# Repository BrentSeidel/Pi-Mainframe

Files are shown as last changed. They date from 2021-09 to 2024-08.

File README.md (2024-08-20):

# Pi-Mainframe
Simulated mainframe computer based on a Raspberry Pi

[]
(https://alire.ada.dev/crates/blinkenlights.html)

When I was a young lad, computers had complicated panels filled with
switches and lights.  Sadly, these disappeared as I got older.

This project is an attempt to recreate the feel of old mainframe computers
using a Raspberry Pi 3 and some other assorted parts that I had laying
around.  The actual boxes and panels are 3D printed.

Here is an example system.  Note that it is fairly modular and the
modules can be attached in different ways.
System Front

Back of system
System Back

## Note
This is still very much a work in progress and things will change.

This project requires 3D printing, making PCBs, soldering, and building
software from source.  It might be a good project for an undergraduate
engineering program.

## Power
I originally used a random micro USB power supply for the Pi 3 that is
running the simulation.  It would complain about low voltage and
occasionally reboot.  I just replaced it with the official Raspberry Pi
power supply and it is not complaining about low voltage.  Time will
tell if it is more stable.

Ultimately, there will be limits to how much power you can get out of
the Raspberry Pi.  There are ways to reduce the power needed.  The first
thing that I would try would be to increase the value of the resistors
for the LEDs.  This would also reduce the brightness so you may wish to
do this as well, if the LEDs are too bright.  A little experimentation
will be needed to determine the proper value.  From a BOM viewpoint,
using the same resistors for both the switches and LEDs would be a win.

## PCBs
Three printed circuit boards have been designed to eliminate some of the
tedious soldering.  Using the PCBs make assembly much easier and the
resulting project much less of a mess of wires.

### IO Board PCB
The I/O board PCB has been created and tested.  The schematics and PCB
layout have been moved to the Circuits reporitory.  Documentation and
assembly instructions for it have been created there.

### Breakout PCB
A breakout PCB has been developed for breaking out the 10 conductor
ribbon cables that are being used for the I2C bus, and other uses.  It
is also in the Circuits repository.

### LED PCB
A PCB has been developed for holding the LEDs.  This required some redesign
to the panels.  However it eliminates the soldering of wires directly to
the LED leads.  The LED PCB can also be fairly easily added to and
removed from panels should you wish to, for example, use LEDs of different
colors.

## Dependencies
This depends on the following repositories:
* https://github.com/BrentSeidel/BBS-Ada.git
* https://github.com/BrentSeidel/BBS-BBB-Ada.git
* https://github.com/BrentSeidel/Ada-Web-Server.git
* https://github.com/BrentSeidel/Things.git
* https://github.com/BrentSeidel/Sim-CPU.git
* https://github.com/BrentSeidel/Circuits.git

If you are actually interested in simulating old computers, you can
download and build simh from github at https://github.com/simh/simh.git
I was able to get the PDP-11 sim to build (I haven't tried others) and
run on a Raspberry Pi.  As far as I know, it has no support for blinking
lights.

You could, of course run simh in parallel with this project giving a
CPU simulation as well as lights and switches.  Unfortunately, they would
be completely independant.  Someday, perhaps this will change.

## Assembly
This project will require quite a bit of 3D printing and soldering.  The
included documentation includes a parts list.  Read the documentation
first, then download the dependencies repositories.  Finally decided
how big of a system you want.
1. Slice the 3D models and start them printing.  This will take a while,
   so start this first and then work on other things while they are printing.
2. Install Raspberian on the Raspberry Pi and install the following packages:
   * avahi - This allows discovery on your local network
   * gnat - The GNU Ada distribution
   * gprbuild - Used for building Ada software
3. Build the software.  If there are errors about missing "obj" directories,
   create the directories.
4. Start soldering the various boards and cables.
5. As panels come off the printer, install LEDs and switches as appropriate
6. As the trays come off the printer, install the boards and connectors.
7. Once everything is printed, put all the pieces together.

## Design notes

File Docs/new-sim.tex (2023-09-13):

\documentclass[10pt, openany]{book}

\usepackage{fancyhdr}
\usepackage{imakeidx}

\usepackage{amsmath}
\usepackage{amsfonts}

\usepackage{geometry}
\geometry{letterpaper}

\usepackage{fancyvrb}
\usepackage{fancybox}

\usepackage{url}
\usepackage{gensymb}
\usepackage{multicol}
\usepackage{tabularx}
%
% Rules to allow import of graphics files in EPS format
%
\usepackage{graphicx}
\DeclareGraphicsExtensions{.eps}
\DeclareGraphicsRule{.eps}{eps}{.eps}{}
%
% Macro definitions
%
\newcommand{\switch}[2]{``#1''/``#2''}
\newcommand{\position}[1]{``#1''}
%
% Front Matter
%
\title{Raspberry Pi Based Mainframe Simulator}
\author{Brent Seidel \\ Phoenix, AZ}
\date{ \today }
%========================================================
%%% BEGIN DOCUMENT
\begin{document}
%
% Produce the front matter
%
\frontmatter
\maketitle
\begin{center}
This document is \copyright 2023 Brent Seidel.  All rights reserved.

\paragraph{}Note that this is a draft version and not the final version for publication.
\end{center}
\tableofcontents
\listoffigures
\listoftables

\mainmatter
%----------------------------------------------------------
\chapter{Introduction}
A rather simplistic view is that this provides a way to get a Raspberry Pi to blink some LEDs and read some switches.  However, this hardware could be modified for a number of other applications that require lots of discrete I/O, such as burglar alarms or sprinkler controls.

\section{Parts}
\subsection{3D Printing}
A fair bit of 3D printing is required, so having lots of filament is a good idea.  Labels on the panels are done by (on my printer with a 0.15mm layer height) printing 2 layers of the panel color, then 3 layers of a contrasting color for the text, and then the rest in the panel color.  The panels are printed with the text faced down.  You may wish to tinker with this for your printer.  The actual parts are:
\begin{itemize}
  \item Four or six racks depending on whether you want a 16 or 32 bit system.
  \item One processor tray.
  \item Two or three discrete I/O trays.
  \item One control panel
  \item One modes panel
  \item Two or four address/data panels (starting at 0, 8, 16, and 24).
\end{itemize}

\subsection{Electronic Parts}
Note that soldering will be required so a soldering station with appropriate tools and solder will be required in addition to the following.
\begin{itemize}
  \item One Raspberry Pi 3B computer (available from many places).
  \item At least four or up to eight MCP23017 I2C 16 bit input/output port expander chips (p/n 732 from Adafruit).
  \item One 28-pin DIP socket per MCP23017.  (eg p/n A120353-ND from Digi-Key)
  \item Recommended one LTC4311 I2C Extender/Active Terminator (p/n 4756 from Adafruit).
  \item One set of Female/Male jumper wires (p/n 1954 from Adafruit).  These are used to connect from the Raspberry Pi to the rest of the circuitry since female connectors are needed on the Raspberry Pi end).
  \item Hookup wire, preferably multi-colored (available from many places).
  \item 36 pin 0.1'' female header (5 pack p/n 598 at Adafruit).  You may need a couple packs.
  \item 23 to 39 Mini panel mount SPDT toggle switches (p/n 3221 from Adafruit).  Feel free to use other switches if you like, though you may need to adjust the hole sizes in the panels.
  \item Lots of 5mm oval LEDs (I used red, but you can use other colors) (eg p/n C5SMF-RJF-CT0W0BB1-ND from Digi-Key (buy a pack of 100 for a price discount, you can always use the excess in other projects)).
  \item Two or three IOBoard PCBs from the Circuits repository.
  \item Several 10-conductor ribbon cable breakout PCBs from the Circuits repository
  \item 4 to 6 LED PCBs from this repository.
\end{itemize}

\subsection{Mechanical Hardware}
I have a Phillips Panhead Electronic Hardware Kit from Digi-Key (p/n 1602-KIT-ND) that has an assortment of machine screws and nuts.  I used these because they were handy.

%----------------------------------------------------------
\chapter{Hardware}

\section{Electronics}
\subsection{Processor}
I had a Raspberry Pi 3 board laying around so I figured that I would use it.  Interestingly, this is a more powerful computer than many of the processors it might be used to simulate.

\subsection{Discrete I/O}
This uses the IOBoard in the Circuits repository.  Two or three of these boards will be required.  Refer to the repository for assembly details.

\section{3D Printed Parts}
\subsection{Racks}
Each rack is a bbs\_rack2(10, 6, 4).  The size is basically constrained by what my 3D printer can do.  Each of these requires about 15 hours to print on my printer.  Two of these can be bolted together side-by-side and fit in a 19 inch rack.  This is the approximate size of the classic computer equipment.  Multiple racks can be bolted together vertically as needed to provide panel space.  Each rack has slots for two vertically oriented trays.

\subsection{Processor Tray}
 The processor tray has mounting holes for the Raspberry Pi processor board. It also has a 10-conductor ribbon cable breakout board for connecting to the I2C bus ribbon cable.  Also on the tray is a LTC4311 I2C Extender/Active Terminator (p/n 4756 from Adafruit).  This may not strictly be necessary, but since the I2C bus will be running off to several other boards, I thought that it might be a good idea..

\subsection{Discrete I/O Tray}
Each of these trays has one IOBoard PCB.  These trays would typically be mounted in the slot next to the panel.  The tray has 4 10-pin connections and can interface with up to 32 GPIOs, typically 16 LEDs and 16 switches.  One additional connector is provided to connect the the power and I2C bus from the processor.

\subsection{Address/Data Panels}
The address/data panels provide 8 switches and LEDs numbered consecutively from right to left.  The starting number is selectable in the model.  Each panel has two cables (one for LEDs and one for switches) that attach to connectors on the discrete I/O boards.  Enough of these need to be provided to account for all the address and data lines in the simulated processor.  A system would typically have two or four of these panels for 16 or 32 bit systems.  Note that there are many cases where the number of address lines does not match the number of data lines.  In these cases panels would need to be provided for whichever number is greater.

\subsection{Control Panel}
At this point, without an actual CPU simulation, this is mostly a way to organize what needs to be in a relatively generic control panel.  The following functions are needed:
\begin{itemize}
  \item Read from a memory location.
  \item Write to a memory location.
  \item Stop/pause processor execution.
  \item Start processor execution at a specified address.
  \item Continue processor execution.
  \item Reset the processor.
\end{itemize}

The following switches are defined on the panel:
\begin{itemize}
  \item \switch{Run}{Pause} - The \position{Run} position allows program execution.  The \position{Pause} position temporarily suspends execution.  Moving the switch back to the \position{Run} position will continue where the program left off.
  \item \switch{Start}{Stop} - Moving the switch to the \position{Start} position loads a starting address to begin program execution.  The \position{Stop} position halts a program and a new starting address will need to be provided.
  \item \switch{Auto}{Man} - The \position{Auto} position allows for remote control of the simulator via a web interface.  The \position{Man} position disables remote control.
  \item \switch{Addr}{Data} - Selects display and entry of memory addresses or data.
  \item \position{Dep} deposits the switch value.  If the \switch{Addr}{Data} switch is in the \position{Addr} position, a memory address is loaded.  If the \switch{Addr}{Data} switch is in the \position{Data} position, the switch value is deposited in memory and the address incremented.
  \item \position{Exam} is used to examine memory at the current address.  The address is incremented each time the switch is moved to the \position{Exam} position.
  \item Spare - an empty position reserved for future expansion.
  \item \switch{Power}{Off} - This will eventually be wired up to control power to the Raspberry Pi computer.
\end{itemize}

\subsubsection{To Specify an Address}
Note that if the word size is greater than 8 bits, some of the lower order address bits may be ignored.
\begin{itemize}
  \item Toggle the desired address using the address/data switches.
  \item Move the \switch{Addr}{Data} switch to the \position{Addr} position.
  \item Move the ``Dep'' (deposit) switch to the \position{Dep} position.
  \item Once the LED for the ``Dep'' switch illuminates, move the switch to the unlabeled position.
\end{itemize}

\subsubsection{To Read Memory}
\begin{itemize}
  \item Specify the starting address as described above.
  \item Move the \switch{Addr}{Data} switch to the \position{Data} position.
  \item Move the ``Exam'' switch to the \position{Exam} position.
  \item The contents of memory at the specified address will be displayed in the Address/Data LEDs.
  \item The \switch{Addr}{Data}  switch can be used to toggle between display of the address and the data.
  \item Move the ``Exam'' switch to the unlabeled position.  This increments the internal address pointer so that by toggling this switch a block of memory can be modified.
\end{itemize}

\subsubsection{To Write Memory}
\begin{itemize}
  \item Specify the starting address as described above.
  \item Move the \switch{Addr}{Data}  switch to the \position{Data} position.
  \item Toggle the desired data using the address/data switches.
  \item Move the ``Dep'' switch to the \position{Dep} position.
  \item The contents of memory at the specified address will be updated and displayed in the Address/Data LEDs.
  \item The \switch{Addr}{Data} switch can be used to toggle between display of the address and the data.
  \item Move the ``Dep'' switch to the unlabeled position.  This increments the internal address pointer so that by toggling this switch a block of memory can be examined.
\end{itemize}

\subsubsection{To Start Execution at a Specific Address}
\begin{itemize}
  \item Move the \switch{Start}{Stop} switch to the \position{Stop} position.
  \item Move the \switch{Addr}{Data} switch to the \position{Addr} position.
  \item Toggle the address using the address/data switches.
  \item Move the \switch{Start}{Stop} switch to the \position{Start} position.
  \item If the \switch{Run}{Pause} switch is in the \position{Pause} position, move it to the \position{Run} position.
\end{itemize}

\subsection{Mode Panel}
This is a display only panel to show the processor and memory access modes.  It has seven labeled positions in two groups separated by a spare.  The first group is the processor mode.  This indicates which of four possible modes (User, Supervisor, Executive, or Kernel) the processor is in.  The second group indicates the type of memory access.  There are four possibilities: Instruction (read-only), Data (read/write), I/O (read/write), and Interrupt (read-only).

\section{Assembly}

\subsection{Planning}
The first decision is if you want to simulate a 16 bit or 32 bit (or something else) system.  Each panel can hold up to 8 LEDs and switches.  Each MCP23017 can control 16 LEDs or switches, so 2 MCP23017s can control 2 panels.  Each rack has space for 1 panel and two circuit trays.  If you attach two racks side by side, they will approximately fit in a 19 inch rack (as I don't have a standard 19 inch rack, you will probably have to design and print some sort of adapter).

Once you've decided on your system size, then you need to figure out how to arrange things.  See Table \ref{tbl:Basic} for an example arrangement.  Once this is finished, then you can go ahead and figure out how long your cables need to be.

\begin{table}[ht!]
  \caption{Example 16 Bit Processor Layout}
  \label{tbl:Basic}
  \centering
  \begin{tabular}{|l|l|}
    \hline
    Processor & empty\\
    Address Data Panel Controller & empty\\
    Address/Data 8-15 Panel & Address/Data 0-7 Panel\\
    \hline
    empty & empty\\
    Control Panel Controller & empty\\
    Mode Panel & Control Panel\\
    \hline
  \end{tabular}
\end{table}

\subsection{Processor Tray}
The processor is an already assembled Raspberry Pi.  I've used a Pi 3B, but others should work as long as they have the same pinout and hole pattern.  What needs to be assembled is the connection from the Pi to the bus.  This starts with the bare breakout board in Figure \ref{fig:BreakoutBare}.  A connector needs to be added as shown in Figure \ref{fig:BreakoutConnector}.  Finally, a female header and jumper wire needs to be added to connect to the Raspberry Pi and make sure that both of the ground conductors are connected to ground as shown in Figure \ref{fig:BreakoutJumper}.

\begin{figure}[ht!]
  \centering
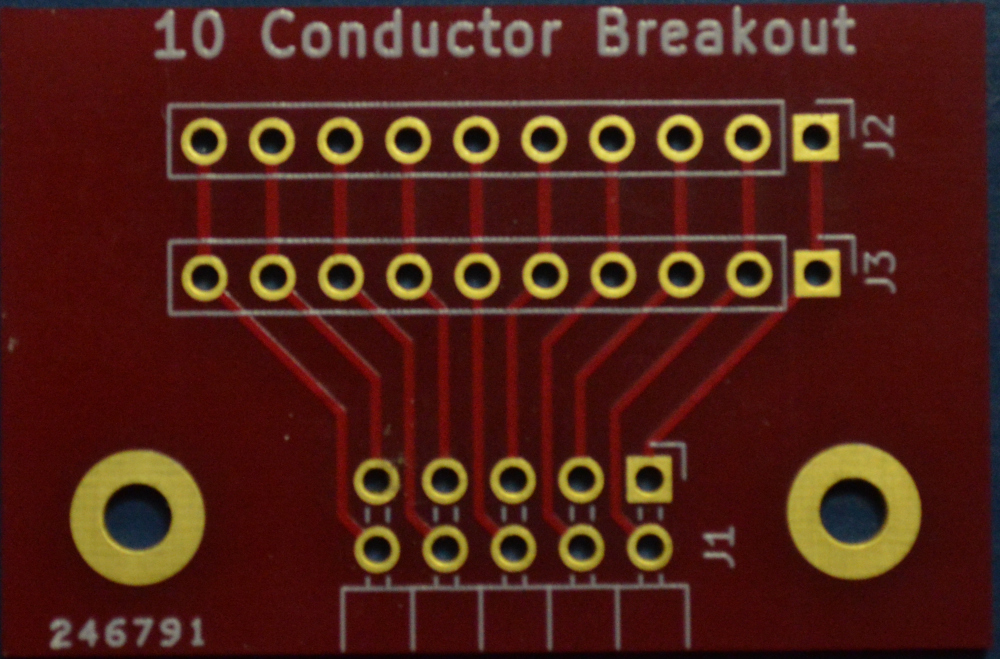
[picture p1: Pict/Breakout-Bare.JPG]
  
  \caption{Bare Breakout Board}
  \label{fig:BreakoutBare}
\end{figure}

\begin{figure}[ht!]
  \centering
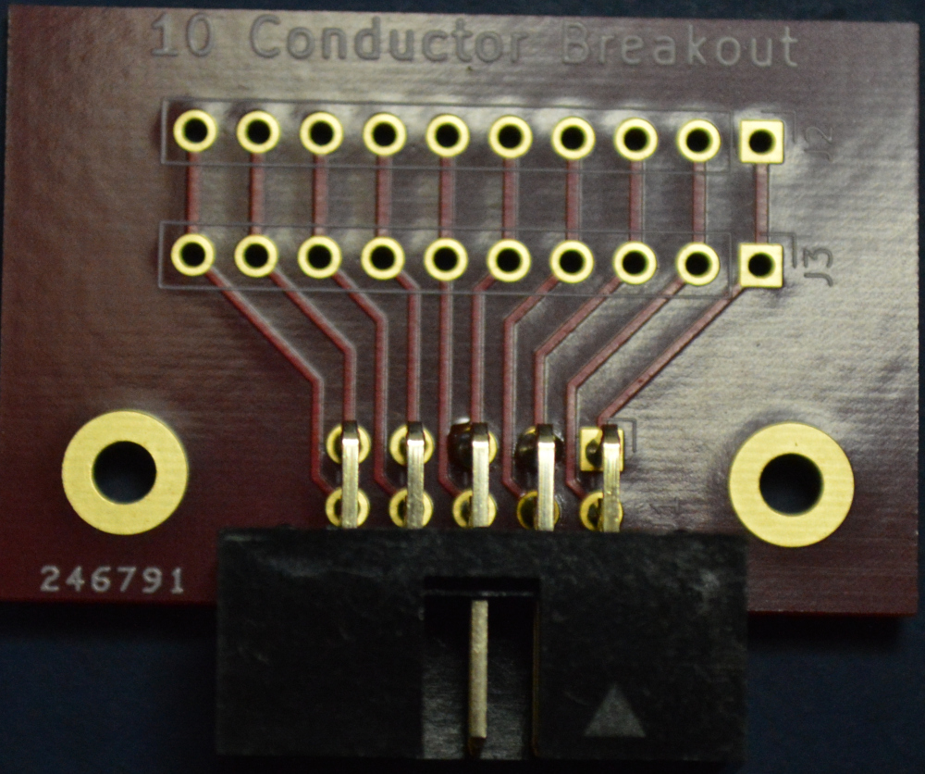
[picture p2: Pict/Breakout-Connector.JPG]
  
  \caption{Breakout Board with Connector}
  \label{fig:BreakoutConnector}
\end{figure}

\begin{figure}[ht!]
  \centering
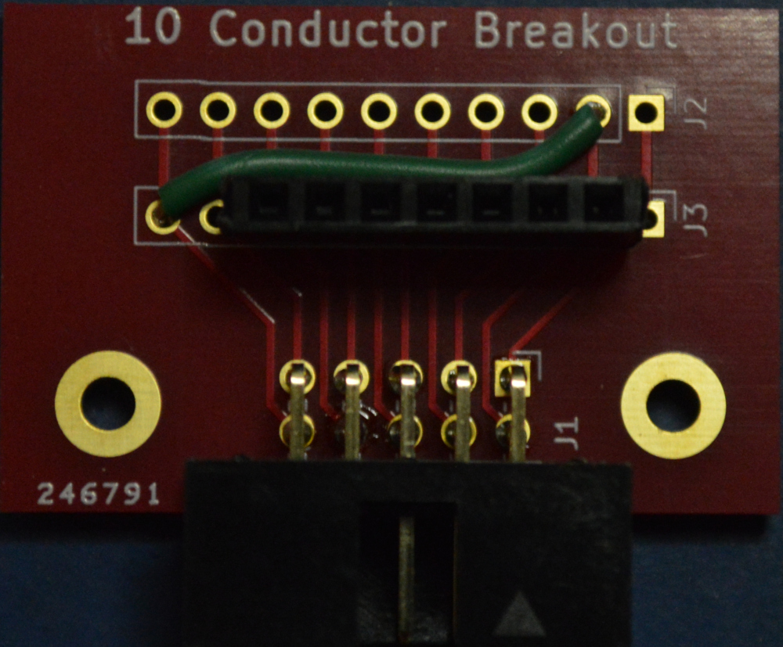
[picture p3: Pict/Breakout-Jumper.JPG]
  
  \caption{Breakout Board with Connectors and Jumper}
  \label{fig:BreakoutJumper}
\end{figure}

\subsubsection{Optional Active Terminator}
Adafruit sells an active I2C terminator that you can connect to the I2C bus to improve the signal quality.  This is optional, but you may wish to consider this if the bus doesn't work properly.  It is soldered to the breakout board by fairly short wires as in Figure \ref{fig:BreakoutDriver}.  The stiffness of these wires should be adequate unless you are expecting high vibrations.  In that case, add mounting holes to the tray so that it can be screwed down.

\begin{figure}[ht!]
  \centering
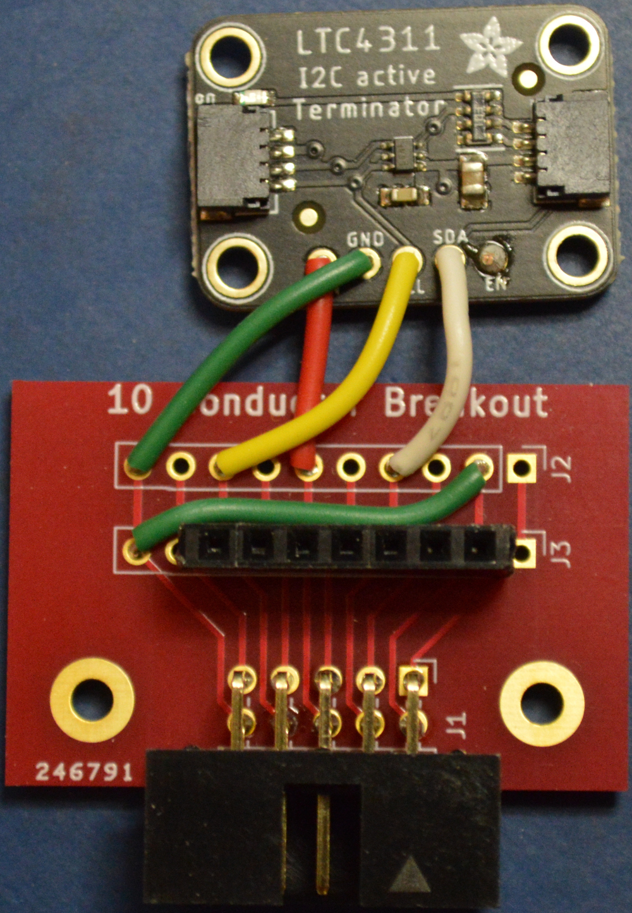
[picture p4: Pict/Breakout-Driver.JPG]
  
  \caption{Breakout Board with Active I2C Terminator}
  \label{fig:BreakoutDriver}
\end{figure}

The one fiddly bit is that a pull-up jumper needs to be added from the Active Terminator's enable pin as show in figure \ref{fig:DriverJumper}.

\begin{figure}[ht!]
  \centering
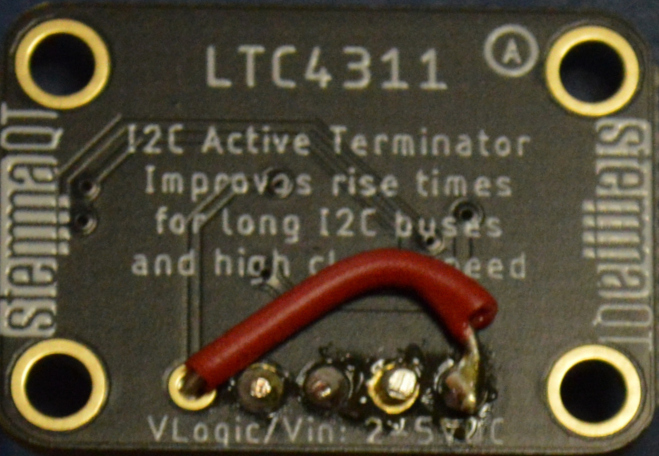
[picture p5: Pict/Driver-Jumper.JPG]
  
  \caption{I2C Active Terminator Showing Pull-Up Jumper to Enable}
  \label{fig:DriverJumper}
\end{figure}

Once the breakout board is assembled, attach it and the Raspberry Pi to the processor tray and add jumper wires from the Pi to the breakout board, as shown in Figure \ref{fig:CPUTray}.

\begin{figure}[ht!]
  \centering
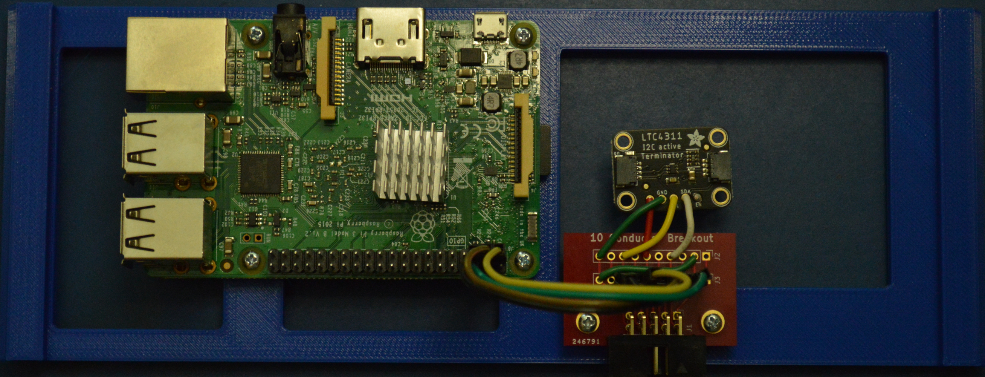
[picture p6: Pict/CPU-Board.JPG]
  
  \caption{Assembled CPU Tray}
  \label{fig:CPUTray}
\end{figure}

\clearpage
\subsection{Panel I/O Tray}
The Panel I/O Tray holds one Discrete I/O Board.  The discrete I/O boards offer 32 bits of GPIO.  Each can be configured as an input or an output.  Assembly instructions for this board are provided in the Circuits repository along with the schematics and PCB layout.

Since the power LED is meant to be on whenever power is applied, a modification needs to be made to the discrete I/O board for the mode and control panels.  This means that the SMD resistor for the power LED needs to be mounted so that it doesn't connect to the MCP23017.  It instead needs a jumper from power connected to it as shown in Figure \ref{fig:GPIOCtrl}.

\begin{figure}[ht!]
  \centering
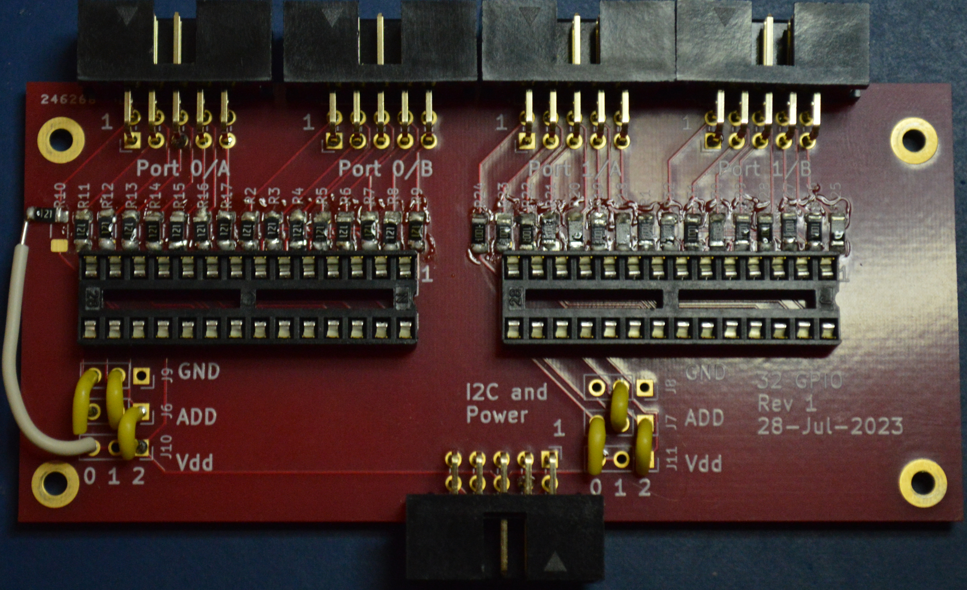
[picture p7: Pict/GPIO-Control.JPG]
  
  \caption{GPIO Board for Mode and Control Panel.  Note jumper to SMD resistor on top left for power indication.}
  \label{fig:GPIOCtrl}
\end{figure}

The I2C addresses and connectors used are in Table \ref{tbl:i2c}.

\begin{table}
  \caption{I2C Addresses for Discrete I/O Boards}
  \label{tbl:i2c}
  \centering
  \begin{tabular}{|l|l|}
    \hline
    Address & Use\\
    0 & Least significant LEDs (port A = bits 7-0, port B = bits 15-8)\\
    1 & Least significant switches (port A = bits 7-0, port B = bits 15-8)\\
    2 & Most significant LEDs (port A = bits 23-16, port B = bits 31-24)\\
    3 & Most significant switches (port A = bits 23-16, port B = bits 31-24)\\
    4 & Mode/Control LEDs (port A = control, port B = mode)\\
    5 & Control switches (port A = control, port B = unused)\\
    6 & Spare for future expansion\\
    7 & Spare for future expansion\\
    \hline
  \end{tabular}
\end{table}

\subsection{Panel LEDs}
\label{subsec:PanelLED}
The LED PCB is shown in Figure \ref{fig:LEDPCB}.  The connector is installed on the opposite side of the board from the LEDs as shown in Figure \ref{fig:LEDConnector}.  This is due to space constraints.  The LEDs are installed as shown in Figure \ref{fig:LEDLED}.  Note that the short leg of the LED goes to ground.  Once the connector is soldered, the LEDs can be inserted and hooked up to an I/O board for testing prior to soldering the LEDs.  The final assembled board after trimming the LED legs is shown in Figure \ref{fig:LEDFinal}.

\begin{figure}[ht!]
  \centering
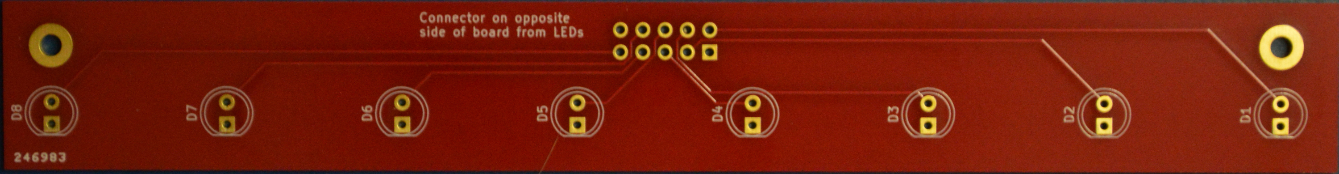
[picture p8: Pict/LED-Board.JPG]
  
  \caption{PCB for LEDs}
  \label{fig:LEDPCB}
\end{figure}

\begin{figure}[ht!]
  \centering
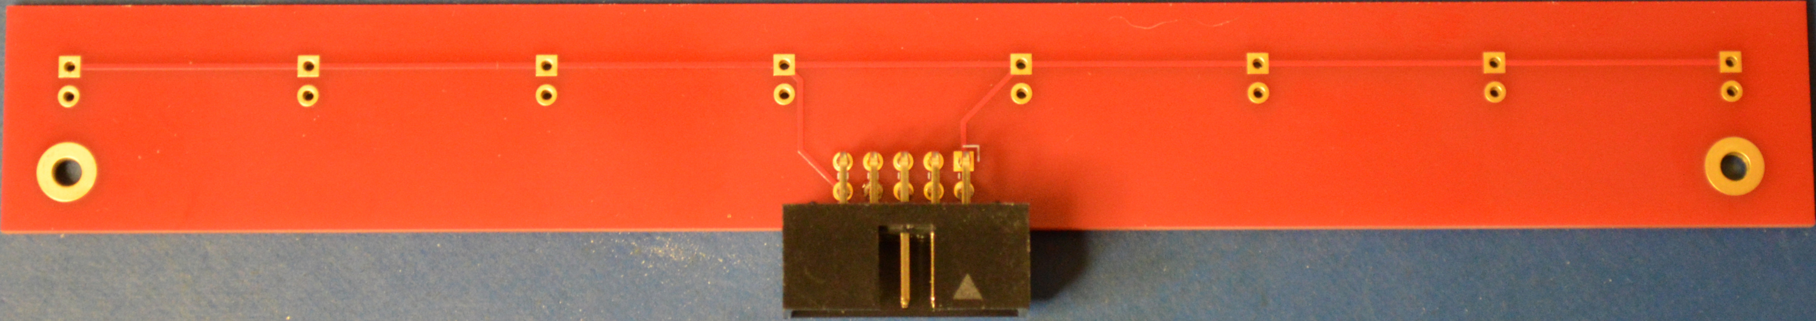
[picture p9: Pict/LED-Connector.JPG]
  
  \caption{LED PCB With Connector Installed}
  \label{fig:LEDConnector}
\end{figure}

\begin{figure}[ht!]
  \centering
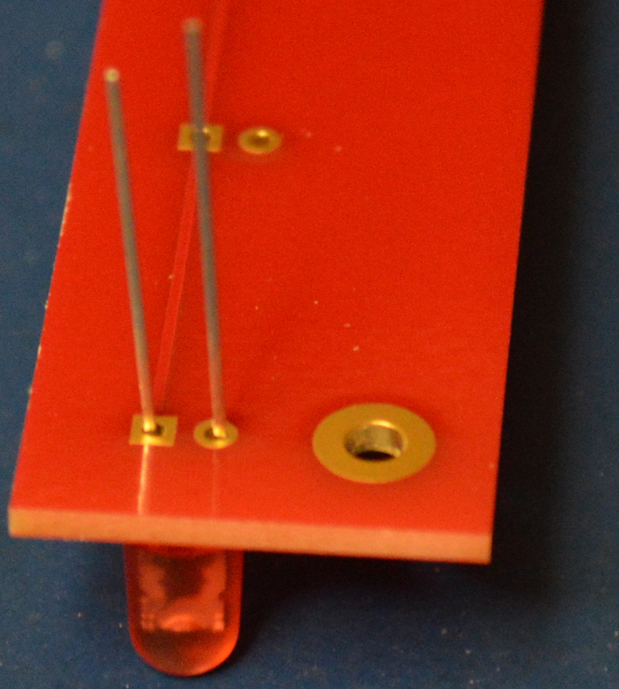
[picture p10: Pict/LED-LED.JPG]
  
  \caption{Installing LEDs in the LED PCB}
  \label{fig:LEDLED}
\end{figure}

\begin{figure}[ht!]
  \centering
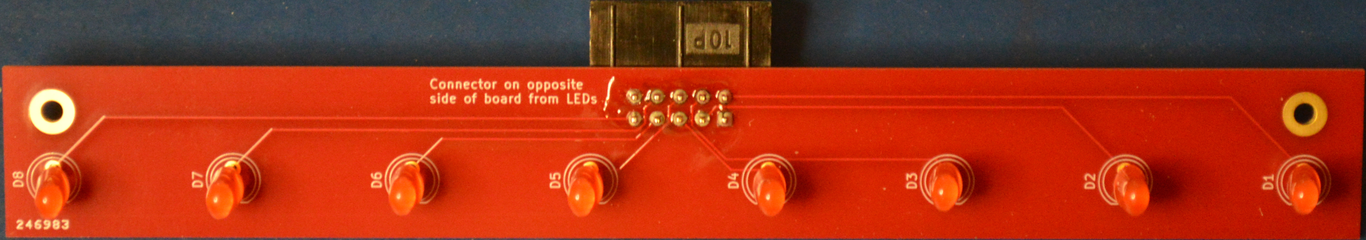
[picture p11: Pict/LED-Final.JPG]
  
  \caption{Completed LED PCB}
  \label{fig:LEDFinal}
\end{figure}

Once the LED PCB is assembled, it is be installed in a panel.  Depending on how accurate the soldering is, some adjustment may need to be done to get the LEDs to go into the holes in the panel.  Once they go, the bottom side of the PCB should be snapped into the groove in the support and screws placed in the top corners.  See Figures \ref{fig:PanelFront} and \ref{fig:PanelBack} for front and back views.

\begin{figure}[ht!]
  \centering
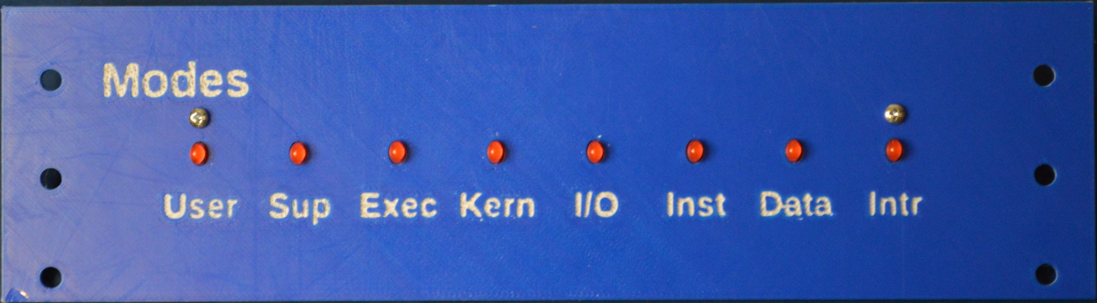
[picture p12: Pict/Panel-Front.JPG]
  
  \caption{Front of Panel with LEDs Installed}
  \label{fig:PanelFront}
\end{figure}

\begin{figure}[ht!]
  \centering
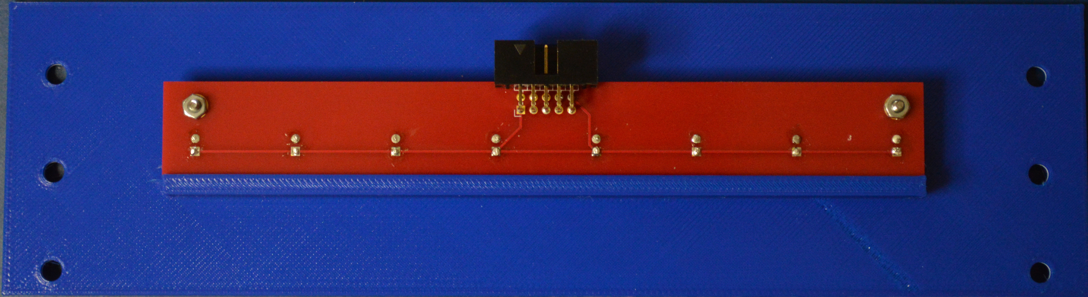
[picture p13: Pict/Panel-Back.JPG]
  
  \caption{Back of Panel with LED PCB Installed}
  \label{fig:PanelBack}
\end{figure}

\clearpage
\subsection{Panel Switches}
My implementation uses SPST switches where the center connector is common.  When the switch is in the up position, the center and lower connector are connected.  When the switch is in the down position, the center and upper connector are connected.  The MCP23017s have an optional pull-up for each input, thus the switches can be used in an open-ground configuration.  The top connectors are tied together and connected to ground.  The center connectors are connected to the individual input pins.
\begin{itemize}
  \item Install the switches as shown in Figure \ref{fig:SwitchInstalled}.
  \item Install the wiring for the switches as shown in Figure \ref{fig:SwitchWired}.  The wiring is shown going to a breakout board.  This allows a ribbon cable to be used to connect to the I/O board.  Alternating blue and white wires are used to make it a little easier to follow.  The ground wire from the breakout board is green on the far right.
\end{itemize}

\begin{figure}[ht!]
  \centering
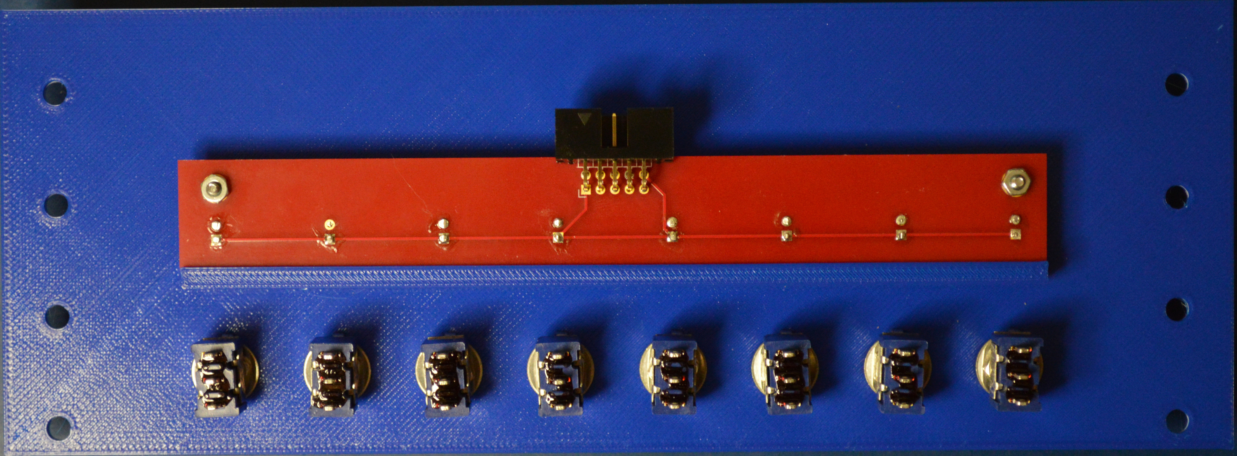
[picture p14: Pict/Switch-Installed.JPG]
  
  \caption{Control Panel Switches Showing Switches Installed}
  \label{fig:SwitchInstalled}
\end{figure}

\begin{figure}[ht!]
  \centering
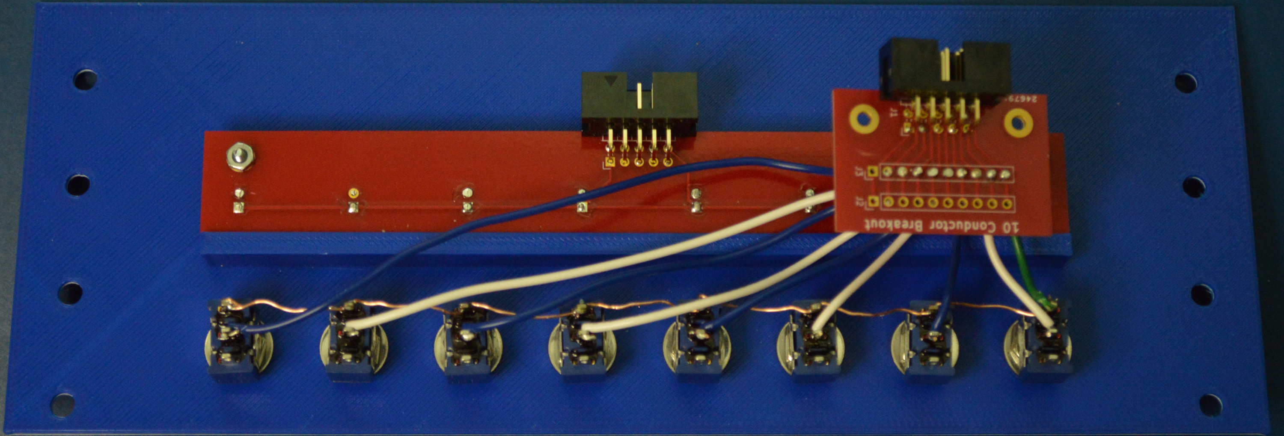
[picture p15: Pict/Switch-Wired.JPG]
  
  \caption{Control Panel Switches Showing Wiring}
  \label{fig:SwitchWired}
\end{figure}

\subsection{I2C Bus Cable}
The I2C Bus Cable is a 10 conductor ribbon cable with crimp-on connectors.  Using this eliminates a lot of tedious soldering that the previous version required.  The pinout for this cable is shown in Table \ref{tbl:I2C-Pins}.

\begin{table}[ht!]
  \caption{I2C Connector Pinout}
  \label{tbl:I2C-Pins}
  \centering
  \begin{tabular}{|r|l|}
    \hline
    Pin & Description\\
    \hline
    1 & No Connection\\
    2 & Ground\\
    3 & No Connection\\
    4 & SDA\\
    5 & No Connection\\
    6 & Vdd\\
    7 & No Connection\\
    8 & SCK\\
    9 & No Connection\\
    10 & Ground\\
    \hline
  \end{tabular}
\end{table}

\section{Power}
You can go with just plugging a USB power adapter into the micro-USB connector on the Raspberry PI, or you can get fancier.  There is a model for a power panel that has cutouts for micro-USB and a USB-B panel mount connectors.  Adafruit offers a number of panel mount USB to various USB adapters.  You can just use one of these.  If you want to get fancier, you can cut open the USB cable and insert the power switch in series with the power conductor.  At this point, you are on your own.  Be careful!

\section{Final Assembly}
Once all of the sub-assemblies are complete, it is time to connect everything together.  It will probably be easiest to start from the bottom and work you way up to the top in assembly.

Since pin 1 of the I/O connectors is on the left side of each connector on the I/O board and LED or switch 1 is on the right side of the panels, the ribbon cables will need a 180$\degree$ twist to them.  When making the I/O cables, put the connector at one end of the cable facing down and the connector at the other end facing up as shown in Figure \ref{fig:GPIOCable}.  On the other hand, the I2C bus cable should have all connectors facing the same direction.

\begin{figure}[ht!]
  \centering
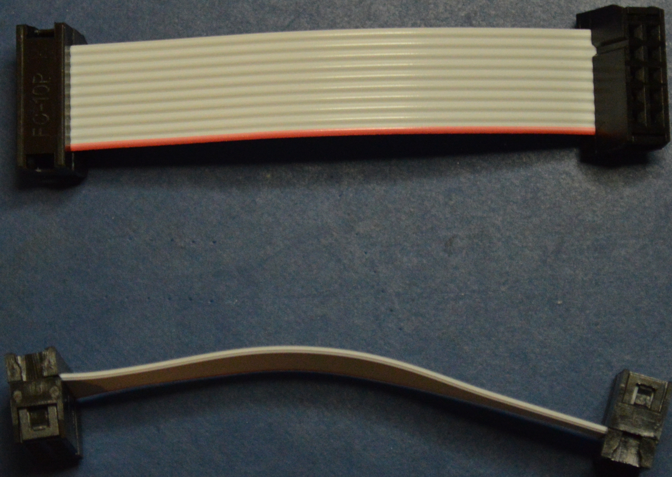
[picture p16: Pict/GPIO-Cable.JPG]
  
  \caption{Example Short GPIO Cables}
  \label{fig:GPIOCable}
\end{figure}

Since there are many options in arranging the various racks, trays, and panels, the lengths of the cables need to be determined on an individual basis.

%----------------------------------------------------------
\chapter{Software}
\section{Overview}
Currently, the software has two main interfaces.  The first is the switches and lights.  The second is a web interface.

\section{Simulation}
The eventual goal is to allow for some actual CPU simulations that use the switches and lights.  Currently, there are some simulations that will blink the lights and look impressive without actually signifying anything.

\begin{table}
  \caption{Simulations Available}
  \label{tbl:Simulations}
  \centering
  \begin{tabular}{|r|l|}
    \hline
    0 & Copy Switch Values\\
    1 & Count\\
    2 & 16-bit Scan\\
    3 & 16-bit Bounce\\
    4 & Fibonacci Sequence\\
    9 & Count\\
    10 & 32-bit Scan\\
    11 & 32-bit Bounce\\
    12 & Fibonacci Sequence\\
    \hline
    other & Copy Switch Values\\
    \hline
  \end{tabular}
\end{table}

There are a number of ``simulations'' available for testing or display.  The desired simulation can be selected either using the switches, or, if enabled, using the web interface.  The following is a description of the control switches:
\begin{itemize}
  \item The \switch{Power}{Off} switch is intended to be hardwired to the power supply.  There is no program function.
  \item The \position{Exam} switch has no current function.
  \item The \position{Dep} switch is used to select which simulation to run.
  \item The \switch{Addr}{Data} switch has no current function.
  \item The \switch{Auto}{Man} switch enables simulation selection by the web interface when in the \position{Auto} position.
  \item The \switch{Start}{Stop} switch sets all simulation variables to their initial state when moved to the \position{Start} position.  It also must be in the \position{Start} position for the simulation to run.
  \item The \switch{Run}{Pause} switch temporarily pauses a simulation when in the \position{Pause} position.  The simulation continues running without initialization when the switch is moved to the \position{Run} position.
\end{itemize}

Note that for a simulation to run, both the \switch{Start}{Stop} switch must be in the \position{Start} position and the \switch{Run}{Pause} switch must be in the \position{Run} position.

On program initialization, simulation 0 (Copy Switch Values) is selected by default.  To select a different simulation, make sure that either the \switch{Run}{Pause} switch is in the \position{Pause} position or the \switch{Start}{Stop} switch is in the \position{Stop} position.  Then:
\begin{itemize}
  \item Using the \switch{Addr}{Data} switches, select the desired simulation as listed in Table \ref{tbl:Simulations}.
  \item Move the \position{Dep} switch to the \position{Dep} position.  You may need to move it to the unlabeled position first.
  \item Move the \position{Dep} switch to the unlabeled position.
  \item Move the \switch{Run}{Pause} switch to the \position{Run} position.
  \item Move the \switch{Start}{Stop} switch to the \position{Start} position.
\end{itemize}

Unless you wish to reset the simulation values, you should always leave the \switch{Start}{Stop} switch in the \position{Start} position.

\section{Web Server}
The web interface is available on port 31415 (configurable in web.adb).  It uses plain, unencrypted HTTP.

\section{Other Software}
To enhance the experience, you can install some old computer emulation software (such as simh, available at \url{https://github.com/simh/simh}).  Note that this will run completely independent from the lights and switch in this project.

\end{document}

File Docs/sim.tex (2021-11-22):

\documentclass[10pt, openany]{book}

\usepackage{fancyhdr}
\usepackage{imakeidx}

\usepackage{amsmath}
\usepackage{amsfonts}

\usepackage{geometry}
\geometry{letterpaper}

\usepackage{fancyvrb}
\usepackage{fancybox}

\usepackage{url}
\usepackage{gensymb}
\usepackage{multicol}
\usepackage{tabularx}
%
% Rules to allow import of graphics files in EPS format
%
\usepackage{graphicx}
\DeclareGraphicsExtensions{.eps}
\DeclareGraphicsRule{.eps}{eps}{.eps}{}
%
% Macro definitions
%
\newcommand{\switch}[2]{``#1''/``#2''}
\newcommand{\position}[1]{``#1''}
%
% Front Matter
%
\title{Raspberry Pi Based Mainframe Simulator}
\author{Brent Seidel \\ Phoenix, AZ}
\date{ \today }
%========================================================
%%% BEGIN DOCUMENT
\begin{document}
%
% Produce the front matter
%
\frontmatter
\maketitle
\begin{center}
This document is \copyright 2021 Brent Seidel.  All rights reserved.

\paragraph{}Note that this is a draft version and not the final version for publication.
\end{center}
\tableofcontents
\listoffigures
\listoftables

\mainmatter
%----------------------------------------------------------
\chapter{Introduction}
A rather simplistic view is that this provides a way to get a Raspberry Pi to blink some LEDs and read some switches.  However, this hardware could be modified for a number of other applications that require lots of discrete I/O, such as burglar alarms or sprinkler controls.

\section{Parts}
\subsection{3D Printing}
A fair bit of 3D printing is required, so having lots of filament is a good idea.  Labels on the panels are done by (on my printer with a 0.15mm layer height) printing 2 layers of the panel color, then 3 layers of a contrasting color for the text, and then the rest in the panel color.  The panels are printed with the text faced down.  You may wish to tinker with this for your printer.  The actual parts are:
\begin{itemize}
  \item Four or six racks depending on whether you want a 16 or 32 bit system.
  \item One processor tray.
  \item Two or three discrete I/O trays.
  \item One control panel
  \item One modes panel
  \item Two or four address/data panels (starting at 0, 8, 16, and 24).
\end{itemize}

\subsection{Electronic Parts}
Note that soldering will be required so a soldering station with appropriate tools and solder will be required in addition to the following.
\begin{itemize}
  \item One Raspberry Pi 3B computer (available from many places).
  \item Four or six half-size perma-proto breadboards (p/n 1609 for qty 1 or p/n 571 for qty 3 from Adafruit)\footnote{Adafruit generally throws one of these in with your order if your order is over \$100}.
  \item One quarter-size perma-proto breadboard (p/n 1608 from Adafruit).
  \item At least four or up to eight MCP23017 I2C 16 bit input/output port expander chips (p/n 732 from Adafruit).
  \item One 28-pin DIP socket per MCP23017.  (eg p/n A120353-ND from Digi-Key)
  \item Recommended one LTC4311 I2C Extender/Active Terminator (p/n 4756 from Adafruit).
  \item One set of Female/Male jumper wires (p/n 1954 from Adafruit).  These are used to connect from the Raspberry Pi to the rest of the circuitry since female connectors are needed on the Raspberry Pi end).
  \item Hookup wire, preferably multi-colored (available from many places).
  \item 36 pin 0.1'' female header (5 pack p/n 598 at Adafruit).  You may need a couple packs.
  \item 23 to 39 Mini panel mount SPDT toggle switches (p/n 3221 from Adafruit).  Feel free to use other switches if you like, though you may need to adjust the hole sizes in the panels.
  \item 11 or 16 female and male DB-9 connectors (eg p/n AE10972-ND (male) and p/n AE11063-ND (female) from Digi-Key (buy a pack of 25 for a price discount)).
  \item Lots of 5mm oval LEDs (I used red, but you can use other colors) (eg p/n C5SMF-RJF-CT0W0BB1-ND from Digi-Key (buy a pack of 100 for a price discount, you can always use the excess in other projects)).
  \item Lots of 120$\Omega$ resistors (eg p/n CF14JT120RCT-ND (lots of other options) from Digi-Key).  These are used for current limiting the LEDs from 3.3V drive.  If you're driving the LEDs with 5V, you'll need a bit more resistance.  Since the Raspberry Pi uses 3.3V, these will work for this project.
  \item A couple meters of CAT-5 cable.  This is for the cables to connect the various assemblies (available from many places).
\end{itemize}

\subsection{Mechanical Hardware}
I have a Phillips Panhead Electronic Hardware Kit from Digi-Key (p/n 1602-KIT-ND) that has an assortment of machine screws and nuts.  I used these because they were handy.

You will need many cable ties.  I have a container of assorted cable ties from Costco.  These can be obtained from many other sources.

%----------------------------------------------------------
\chapter{Hardware}

\section{Electronics}
\subsection{Processor}
I had a Raspberry Pi 3 board laying around so I figured that I would use it.  Interestingly, this is a more powerful computer than many of the processors it might be used to simulate.

\subsection{Discrete I/O}
Each of these boards in built on a 1/2 size perma-proto board from Adafruit.  It has one MCP23017 16 bit I/O expander chip with I2C interface in a socket.  Three pins are provided to configure the address, so the system can have up to 8 of these chips or 128 discrete I/O pins.  There is space on the board for 8 current limiting resistors for LED drive.

\section{3D Printed Parts}
\subsection{Racks}
Each rack is a bbs\_rack2(10, 6, 4).  The size is basically constrained by what my 3D printer can do.  Each of these requires about 15 hours to print on my printer.  Two of these can be bolted together side-by-side and fit in a 19 inch rack.  This is the approximate size of the classic computer equipment.  Multiple racks can be bolted together vertically as needed to provide panel space.  Each rack has slots for two vertically oriented trays.

\subsection{Processor Tray}
 The processor tray has mounting holes for the Raspberry Pi processor boad. It also has a 1/4 size perma-proto board from Adafruit (this may get changed to a half sized board) to provide space for miscellaneous wiring.  Also on the tray is a LTC4311 I2C Extender/Active Terminator (p/n 4756 from Adafruit).  This may not strictly be necessary, but since the I2C bus will be running off to several other boards, I thought that it might be a good idea.  There is also a DB-9 connector that carries power and the I2C bus to the other trays.

\subsection{Discrete I/O Tray}
Each of these trays has one or two MCP23017 16 bit I/O expander chips with I2C interface.  These trays would typically be mounted in the slot next to the panel.  The tray has 4 DB-9 connections and can interface with up to  16 LEDs and 16 switches.  One additional DB-9 connection is provided to connect the the power and I2C bus from the processor.

\subsection{Address/Data Panels}
The address/data panels provide 8 switches and LEDs numbered consecutively from right to left.  The starting number is selectable in the model.  Each panel has two cables (one for LEDs and one for switches) that attach to connectors on the discrete I/O boards.  Enough of these need to be provided to account for all the address and data lines in the simulated processor.  A system would typically have two or four of these panels for 16 or 32 bit systems.  Note that there are many cases where the number of address lines does not match the number of data lines.  In these cases panels would need to be provided for whichever number is greater.

\subsection{Control Panel}
At this point, without an actual CPU simulation, this is mostly a way to organize what needs to be in a relatively generic control panel.  The following functions are needed:
\begin{itemize}
  \item Read from a memory location.
  \item Write to a memory location.
  \item Stop/pause processor execution.
  \item Start processor execution at a specified address.
  \item Continue processor execution.
  \item Reset the processor.
\end{itemize}

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

\subsubsection{To Specify an Address}
Note that if the word size is greater than 8 bits, some of the lower order address bits may be ignored.
\begin{itemize}
  \item Toggle the desired address using the address/data switches.
  \item Move the \switch{Addr}{Data} switch to the \position{Addr} position.
  \item Move the ``Dep'' (deposit) switch to the \position{Dep} position.
  \item Once the LED for the ``Dep'' switch illuminates, move the switch to the unlabeled position.
\end{itemize}

\subsubsection{To Read Memory}
\begin{itemize}
  \item Specify the starting address as described above.
  \item Move the \switch{Addr}{Data} switch to the \position{Data} position.
  \item Move the ``Exam'' switch to the \position{Exam} position.
  \item The contents of memory at the specified address will be displayed in the Address/Data LEDs.
  \item The \switch{Addr}{Data}  switch can be used to toggle between display of the address and the data.
  \item Move the ``Exam'' switch to the unlabeled position.  This increments the internal address pointer so that by toggling this switch a block of memory can be modified.
\end{itemize}

\subsubsection{To Write Memory}
\begin{itemize}
  \item Specify the starting address as described above.
  \item Move the \switch{Addr}{Data}  switch to the \position{Data} position.
  \item Toggle the desired data using the address/data switches.
  \item Move the ``Dep'' switch to the \position{Dep} position.
  \item The contents of memory at the specified address will be updated and displayed in the Address/Data LEDs.
  \item The \switch{Addr}{Data} switch can be used to toggle between display of the address and the data.
  \item Move the ``Dep'' switch to the unlabeled position.  This increments the internal address pointer so that by toggling this switch a block of memory can be examined.
\end{itemize}

\subsubsection{To Start Execution at a Specific Address}
\begin{itemize}
  \item Move the \switch{Start}{Stop} switch to the \position{Stop} position.
  \item Move the \switch{Addr}{Data} switch to the \position{Addr} position.
  \item Toggle the address using the address/data switches.
  \item Move the \switch{Start}{Stop} switch to the \position{Start} position.
  \item If the \switch{Run}{Pause} switch is in the \position{Pause} position, move it to the \position{Run} position.
\end{itemize}

\subsection{Mode Panel}
This is a display only panel to show the processor and memory access modes.  It has seven labeled positions in two groups separated by a spare.  The first group is the processor mode.  This indicates which of four possible modes (User, Supervisor, Executive, or Kernel) the processor is in.  The second group indicates the type of memory access.  There are three possibilities: Instruction (read-only), Data (read/write), and Interrupt (read-only).

\section{Assembly}

\subsection{Planning}
The first decision is if you want to simulate a 16 bit or 32 bit (or something else) system.  Each panel can hold up to 8 LEDs and switches.  Each MCP23017 can control 16 LEDs or switches, so 2 MCP23017s can control 2 panels.  Each rack has space for 1 panel and two circuit trays.  If you attach two racks side by side, they will approximately fit in a 19 inch rack (as I don't have a standard 19 inch rack, you will probably have to design and print some sort of adapter).

Once you've decided on your system size, then you need to figure out how to arrange things.  See Table \ref{tbl:Basic} for an example arrangement.  Upon assembling this system, I discovered a drawback--the top of the Control Panel Controller interferes with the cable connecting the controllers to the processor.  An improved arrangement is in Table \ref{tbl:Improved}.

Once your arrangement is finished, then you can go ahead and figure out how long your cables need to be.  After you have the cables from the panels to the controllers finished, it becomes much harder to move things around.  Ask me how I know.

\begin{table}
  \label{tbl:Basic}
  \caption{Example 16 Bit Processor Layout}
  \centering
  \begin{tabular}{|l|l|}
    \hline
    Processor & empty\\
    Address Data Panel Controller & empty\\
    Address/Data 8-15 Panel & Address/Data 0-7 Panel\\
    \hline
    empty & empty\\
    Control Panel Controller & empty\\
    Mode Panel & Control Panel\\
    \hline
  \end{tabular}
\end{table}

\begin{table}
  \label{tbl:Improved}
  \caption{Improved 16 Bit Processor Layout}
  \centering
  \begin{tabular}{|l|l|}
    \hline
    Processor & empty\\
    empty & Address Data Panel Controller\\
    Address/Data 8-15 Panel & Address/Data 0-7 Panel\\
    \hline
    empty & empty\\
    Control Panel Controller & empty\\
    Mode Panel & Control Panel\\
    \hline
  \end{tabular}
\end{table}

\subsection{Discrete I/O Boards}
The discrete I/O boards offer 16 bits of GPIO.  Each can be configured as an input or an output.  There is not enough space on the breadboard for 16 current limiting resistors for LEDs.  So, the design has 8 resistors on each board.  Two boards are used on a panel I/O tray.  One board drives the LEDs and one reads the switches.  The LED board uses the 8 resistors on itself as well at the 8 resistors on the switch board.
\begin{itemize}
  \item First, solder the resistors and socket.  See Figure \ref{fig:GPIO1}.
  \item Then add some fixed wires.  See Figure \ref{fig:GPIO2}.
  \item Solder in the female header strips.  Some of these can be omitted and the wires in the next step soldered in directly, but having these will make reconfiguration easier.  See Figure \ref{fig:GPIO3}.
  \item Add local wires to the header strips.  You may wish to wait until the board is installed in the Panel I/O Tray before doing this.
\end{itemize}

\begin{figure}[ht!]
  \centering
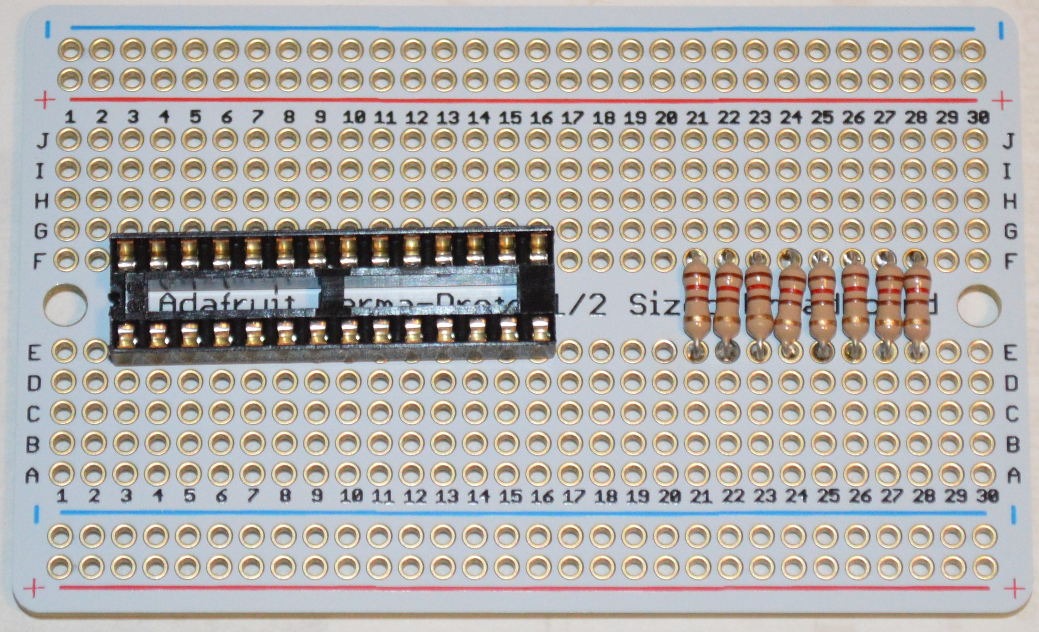
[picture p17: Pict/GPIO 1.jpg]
  
  \caption{GPIO Board with Socket and Resistors}
  \label{fig:GPIO1}
\end{figure}

\begin{figure}[ht!]
  \centering
  
  \caption{GPIO Board with Socket, Resistors, and Fixed Wires}
  \label{fig:GPIO2}
\end{figure}

\begin{figure}[ht!]
  \centering
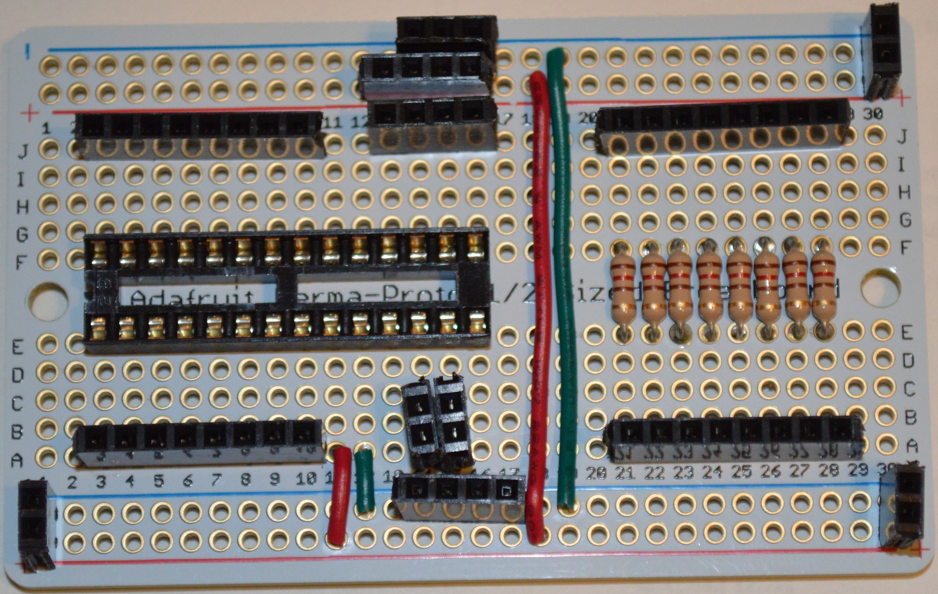
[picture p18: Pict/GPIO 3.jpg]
  
  \caption{GPIO Board with Headers}
  \label{fig:GPIO3}
\end{figure}

\clearpage
\subsection{Panel I/O Tray}
There are two discrete I/O boards on this tray.  Together they can drive up to 16 LEDs and read 16 switches.  The left board drives the LEDs and the right board reads the switches.  The connectors from left to right are: MSB LEDs, MSB switches, LSD switches, and LSB LEDs.

It turns out that 8 of the 16 GPIO pins on the MCP23017 are numbered ascending down one side of the chip and the other 8 are numbered descending down the other side.  To account for this, you can either have the jumpers cross over for two of the panel connectors (I did this in the first version), or simply rotate two of the connectors by 180\degree{}, thus putting the twist into the cable.
\begin{itemize}
  \item Attach the connectors to the tray.  See Figure \ref{fig:PanelIO1}.
  \item Attach the two Discrete I/O Boards.  See Figure \ref{fig:PanelIO2}.
  \item Add wiring for power, I2C, and board configuration (Figure \ref{fig:PanelIO3} shows the address and reset jumpers installed.  From the address jumpers, these are the control LED and control switch boards) and install the MCP23017s.  See Figure \ref{fig:PanelIO4}.  If the processor and bus cable are ready, this can be hooked up to see that the processor detects the MCP23017s.
  \item Add wiring to the connectors.  See Figures \ref{fig:PanelIO5}, \ref{fig:PanelIO6}, and \ref{fig:PanelIO7}.  Also refer to subsection \ref{subsec:PanelLED} to make sure that the connector pinouts match those of the panel being connected.
\end{itemize}

\begin{figure}[ht!]
  \centering
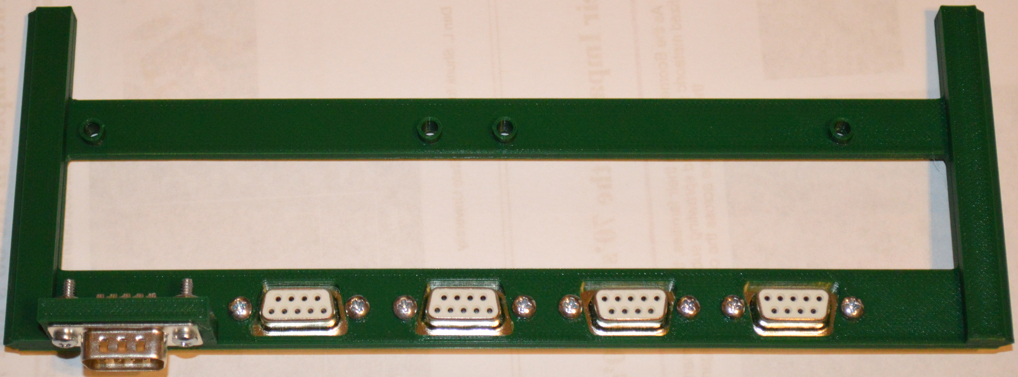
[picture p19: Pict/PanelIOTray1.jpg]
  
  \caption{Panel I/O Tray with Connectors}
  \label{fig:PanelIO1}
\end{figure}

\begin{figure}[ht!]
  \centering
  
  \caption{Panel I/O Tray with GPIO Boards}
  \label{fig:PanelIO2}
\end{figure}

\begin{figure}[ht!]
  \centering
  
  \caption{Panel I/O Tray with GPIO Boards with Address and Reset Jumpers Installed.  These are Control LED and Control Switch Boards}
  \label{fig:PanelIO3}
\end{figure}

\begin{figure}[ht!]
  \centering
  
  \caption{Panel I/O Tray with GPIO Boards with Power, I2C, and MPC23017s Installed}
  \label{fig:PanelIO4}
\end{figure}

\begin{figure}[ht!]
  \centering
  
  \caption{Panel I/O Tray with LSB LED and Switch Connectors Wired}
  \label{fig:PanelIO5}
\end{figure}

\begin{figure}[ht!]
  \centering
  
  \caption{Panel I/O Tray with MSB LED and Switch Connectors Wired}
  \label{fig:PanelIO6}
\end{figure}

\begin{figure}[ht!]
  \centering
  
  \caption{Back Side of Panel I/O Tray Showing Connector Wiring}
  \label{fig:PanelIO7}
\end{figure}

\clearpage
\subsection{I2C Bus Cable}
The I2C bus cable is probably the most difficult bit of soldering as you will have to add two wires to each contact in a connector.  Multiple times.  Which pairs are used for which pins isn't particularly important, but I wire pins 2 \& 6, 2 \& 7, 4 \& 8, and 5 \& 9 as pairs.  Pin 3 is left unconnected.  It is obviously important to have the same wire go to the same pin on each connector on the bus.  Figure \ref{fig:Cable1} shows an example cable.  Figure \ref{fig:Cable2} is a close-up of one of the connectors.  It is a little easier to decide ahead of time how many connectors you want on the bus.  Soldering a cable segment to an existing connector can be done, but is more difficult.

\begin{figure}[ht!]
  \centering
  
  \caption{The I2C Bus Cable}
  \label{fig:Cable1}
\end{figure}

\begin{figure}[ht!]
  \centering
  
  \caption{An I2C Bus Cable Connector}
  \label{fig:Cable2}
\end{figure}

\clearpage
\subsection{Panel LEDs}
\label{subsec:PanelLED}
The wiring for the panel LEDs is similar for all panels.  The Modes Panel is shown as an example.  The LEDs on the other panels would be wired the same way.  Note the cable ties used to attach the wiring to the panel.  This also helps to keep the LEDs in place so that they don't push out.

You can choose whatever pinout you want for the connectors, however it helps if there is some reason and consistency behind it.  What I have done is to look at the connector from the back with the wide side up and assign the pins in the same order as the LEDs or switches, with the very middle pin assigned to ground (as shown in Figure \ref{fig:LED5}.  That is, the left-most pin corresponds to the left-most LED or switch, and so on.

\begin{itemize}
  \item Since CAT-5 cables are only 8 conductor, a separate ground/return wire needs to be added.  As a note of caution, I find that the orange and brown pairs are difficult to distinguish.  Be careful, otherwise you may wind up having to resolder the connector.  See Figure \ref{fig:LED5}.
  \item First using a cable tie, attach the cable to the panel.  This helps to keep the cable from moving around while the LEDs are soldered.  There is also a bare copper wire used as a ground/return wire for the LEDs.  See Figure \ref{fig:LED1}.
  \item Solder the first LED to one side of the cable.  This one is the hardest as there is only a short length of wire to work with.  See Figure \ref{fig:LED2}.
  \item Solder the next LED and add a cable tie between them.  See Figure \ref{fig:LED3}.
  \item Solder the remaining LEDs on that side and add cable ties between them.  See Figure \ref{fig:LED4}.
  \item Find a place to solder the ground/return wire from the connector to the bare LED ground/return wire.  See Figure \ref{fig:LED6}.
  \item Complete the other side of the panel.  See Figure \ref{fig:LED6}.
  \item At some point, you may wish to trim the leads on the LEDs.
\end{itemize}

\begin{figure}[ht!]
  \centering
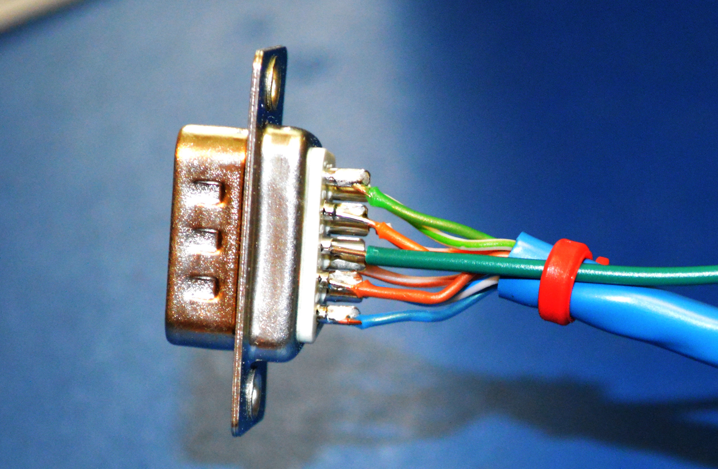
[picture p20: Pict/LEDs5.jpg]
  
  \caption{LED Panel Connector with Ground Wire}
  \label{fig:LED5}
\end{figure}

\begin{figure}[ht!]
  \centering
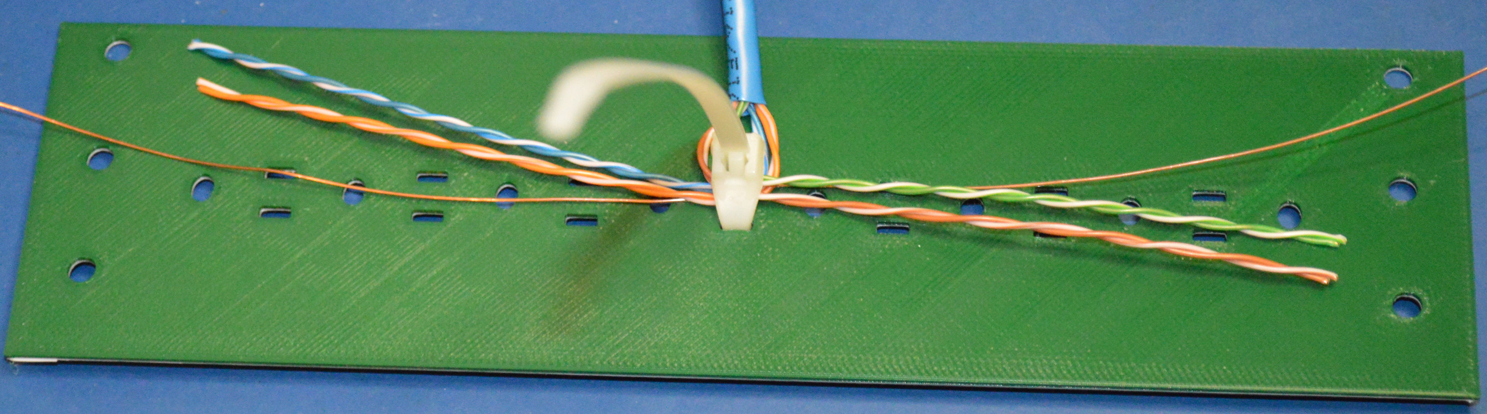
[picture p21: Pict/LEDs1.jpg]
  
  \caption{Attach the Cable to the Panel}
  \label{fig:LED1}
\end{figure}

\begin{figure}[ht!]
  \centering
  
  \caption{Solder the First LED}
  \label{fig:LED2}
\end{figure}

\begin{figure}[ht!]
  \centering
  
  \caption{Solder the Second LED and Add a Cable Tie}
  \label{fig:LED3}
\end{figure}

\begin{figure}[ht!]
  \centering
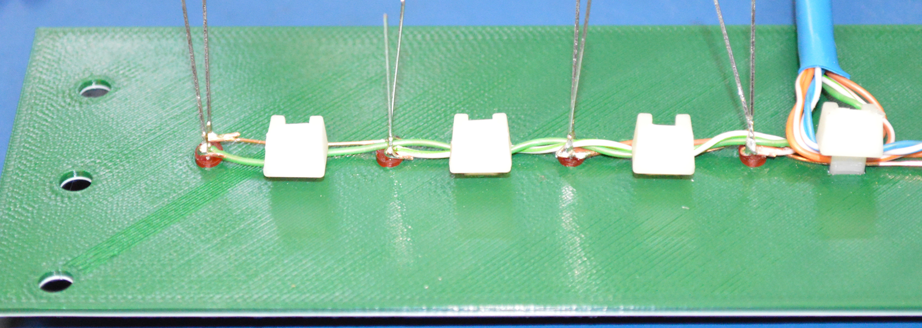
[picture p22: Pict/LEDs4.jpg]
  
  \caption{Solder the Remaining LEDs on That Side and Add Cable Ties}
  \label{fig:LED4}
\end{figure}

\begin{figure}[ht!]
  \centering
  
  \caption{The Completed Panel}
  \label{fig:LED6}
\end{figure}

\clearpage
\subsection{Panel Switches}
My implementation uses SPST switches where the center connector is common.  When the switch is in the up position, the center and lower connector are connected.  When the switch is in the down position, the center and upper connector are connected.  The MCP23017s have an optional pullup for each input, thus the switches can be used in an open-ground configuration.  The top connectors are tied together and connected to ground.  The center connectors are connected to the individual input pins.
\begin{itemize}
  \item Install the switches as shown in Figure \ref{fig:Switch1}.  This example shows a control panel that only has six switches.
  \item Install the wiring for the switches as shown in Figure \ref{fig:Switch2}.  Since the control panel has only six switches, one of the cable pairs is unused.
  \item Finally, install the LEDs in the panel as described in Section \ref{subsec:PanelLED} and shown in Figure \ref{fig:Switch3}.
\end{itemize}
\begin{figure}[ht!]
  \centering
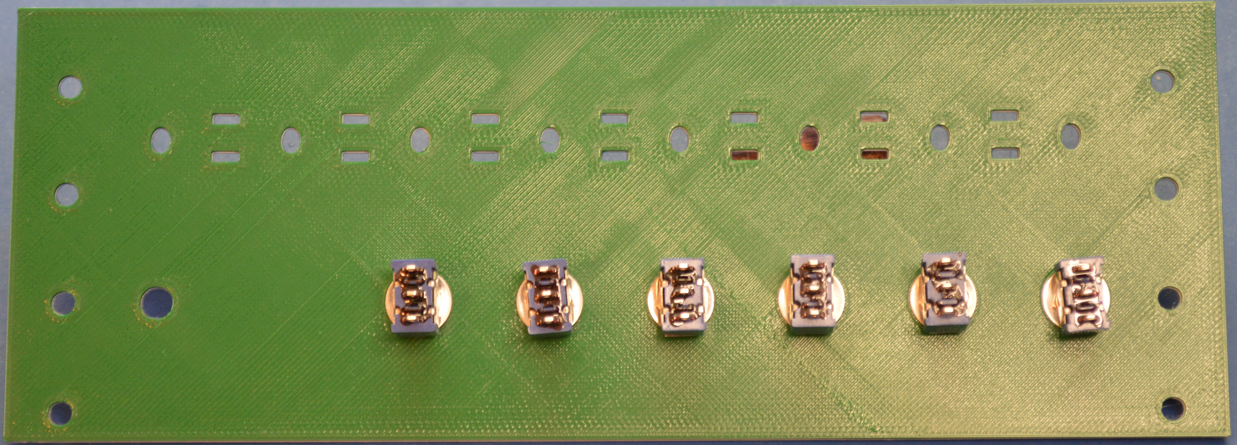
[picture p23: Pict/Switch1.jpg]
  
  \caption{Control Panel Switches Showing Switches Installed}
  \label{fig:Switch1}
\end{figure}

\begin{figure}[ht!]
  \centering
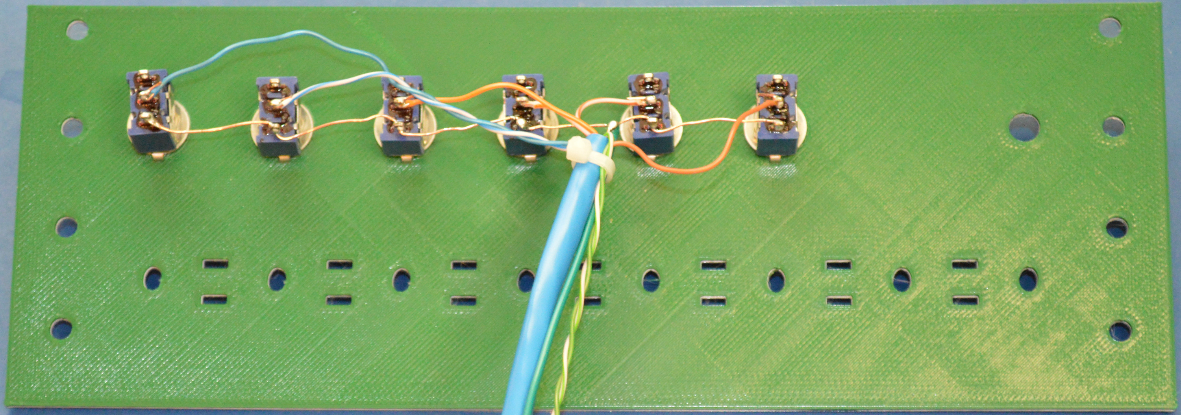
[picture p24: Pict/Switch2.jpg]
  
  \caption{Control Panel Switches Showing Wiring}
  \label{fig:Switch2}
\end{figure}

\begin{figure}[ht!]
  \centering
  
  \caption{Control Panel with Switches and LEDs Installed and Wired}
  \label{fig:Switch3}
\end{figure}

\section{Power}
You can go with just plugging a USB power adapter into the micro-USB connector on the Raspberry PI, or you can get fancier.  There is a model for a power panel that has cutouts for micro-USB and a USB-B panel mount connectors.  Adafruit offers a number of panel mount USB to various USB adapters.  You can just use one of these.  If you want to get fancier, you can cut open the USB cable and insert the power switch in series with the power conductor.  At this point, you are on your own.  Be careful!

%----------------------------------------------------------
\chapter{Software}
\section{Overview}
Currently, the software has two main interfaces.  The first is the switches and lights.  The second is a web interface.

\section{Simulation}

\begin{table}
  \label{tbl:Simulations}
  \caption{Simulations Available}
  \centering
  \begin{tabular}{|r|l|}
    \hline
    0 & Copy Switch Values\\
    1 & Count\\
    2 & 16-bit Scan\\
    3 & 16-bit Bounce\\
    4 & Fibonacci Sequence\\
    9 & Count\\
    10 & 32-bit Scan\\
    11 & 32-bit Bounce\\
    12 & Fibonacci Sequence\\
    \hline
    other & Copy Switch Values\\
    \hline
  \end{tabular}
\end{table}

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

Note that for a simulation to run, both the \switch{Start}{Stop} switch must be in the \position{Start} position and the \switch{Run}{Pause} switch must be in the \position{Run} position.

On program initialization, simulation 0 (Copy Switch Values) is selected by default.  To select a different simulation, make sure that either the \switch{Run}{Pause} switch is in the \position{Pause} position or the \switch{Start}{Stop} switch is in the \position{Stop} position.  Then:
\begin{itemize}
  \item Using the \switch{Addr}{Data} switches, select the desired simulation as listed in Table \ref{tbl:Simulations}.
  \item Move the \position{Dep} switch to the \position{Dep} position.  You may need to move it to the unlabeled position first.
  \item Move the \position{Dep} switch to the unlabeled position.
  \item Move the \switch{Run}{Pause} switch to the \position{Run} position.
  \item Move the \switch{Start}{Stop} switch to the \position{Start} position.
\end{itemize}

Unless you wish to reset the simulation values, you should always leave the \switch{Start}{Stop} switch in the \position{Start} position.

\section{Web Server}
The web interface is available on port 31415 (configurable in web.adb).  It uses plain, unencrypted HTTP.

\section{Other Software}
To enhance the experience, you can install some old computer emulation software (such as simh, available at https://github.com/simh/simh).  Note that this will run completely independent from the lights and switch in this project.

\end{document}

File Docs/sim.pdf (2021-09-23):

# Raspberry Pi Based Mainframe Simulator

Brent Seidel
Phoenix, AZ

September 23, 2021

ii

This document is

c 2021 Brent Seidel. All rights reserved.

Note that this is a draft version and not the final version for publication.

# Contents

1 Introduction | 1
2 Hardware | 3
3 Software | 7

iii

iv | CONTENTS

# Chapter 1

# Introduction

A rather simplistic view is that this provides a way to get a Raspberry Pi to blink some LEDs and read some switches. However, this hardware could be modified for a number of other applications that require lots of discrete I/O, such as burglar alarms or sprinkler controls.

## 1.1 Parts

1.1.1 3D Printing

A fair bit of 3D printing is required, so having lots of filament is a good idea. Labels on the panels are done by (on my printer with a 0.15mm layer height) printing 2 layers of the panel color, then 3 layers of a contrasting color for the text, and then the rest in the panel color. The panels are printed with the text faced down. You may wish to tinker with this for your printer. The actual parts are:

- Four or six racks depending on whether you want a 16 or 32 bit system.
- One processor tray.
- Two or three discrete I/O trays.
- One control panel
- One modes panel
- Two or four address/data panels (starting a 9, 8, 16, and 24).

### 1.1.2 Electronic Parts

Note that soldering will be required so a soldering station with appropriate tools and solder will be required in addition to the following.

- One Raspberry Pi 3B computer (available from many places).

1

2 | CHAPTER 1. INTRODUCTION
| • Four or six half-size perma-proto breadboards (p/n 1609 for qty 1 or p/n 571 for qty 3 from
Adafruit)¹
| • One quarter-size perma-proto breadboard (p/n 1608 from Adafruit).
| • At least four or up to eight MCP23017 I2C 16 bit input/output port expander chips (p/n 732
from Adafruit).
| • Recommended one LTC4311 I2C Extender/Active Terminator (p/n 4756 from Adafruit).
| • One set of Female/Male jumper wires (p/n 1954 from Adafruit). These are used to connect from the Raspberry Pi to the rest of the circuitry since female connectors are needed on the

Raspberry Pi end).

| • Hookup wire, preferably multi-colored (available from many places).
| • 36 pin 0.1” female header (5 pack p/n 598 at Adafruit). You may need a couple packs.
| • 23 to 39 Mini panel mount SPDT toggle switches (p/n 3221 from Adafruit). Feel free to use other switches if you like, though you may need to adjust the hole sizes in the panels.
| • 11 or 16 female and male DB-9 connectors (eg p/n AE10972-ND (male) and p/n AE11063-ND (female) from Digi-Key (buy a pack of 25 for a price discount)).
| • Lots of 5mm oval LEDs (I used red, but you can use other colors) (eg p/n C5SMF-RJF- CT0W0BB1-ND from Digi-Key (buy a pack of 100 for a price discount, you can always use

the excess in other projects)).

| • Lots of 120Ω resistors (eg p/n CF14JT120RCT-ND (lots of other options) from Digi-Key). These are used for current limiting the LEDs from 3.3V drive. If you’re driving the LEDs with 5V, you’ll need a bit more resistance. Since the Raspberry Pi uses 3.3V, these will work

for this project.

| • A couple meters of CAT-5 cable. This is for the cables to connect the various assemblies
(available from many places).

### 1.1.3 Mechanical Hardware

I have a Phillips Panhead Electronic Hardware Kit from Digi-Key (p/n 1602-KIT-ND) that has an assortment of machine screws and nuts. I used these because they were handy.
| You will need many cable ties. I have a container of assorted cable ties from Costco. These can
be obtained from many other sources.

1Adafruit generally throws one of these in with your order if your order is over $100

# Chapter 2

# Hardware

## 2.1 Electronics

### 2.1.1 Processor

I had a Raspberry Pi 3 board laying around so I figured that I would use it. Interestingly, this is a more powerful computer than many of the processors it might be used to simulate.

### 2.1.2 Discrete I/O

Each of these boards in built on a 1/2 size perma-proto board from Adafruit. It has one MCP23017 16 bit I/O expander chip with I2C interface in a socket. Three pins are provided to configure the address, so the system can have up to 8 of these chips or 128 discrete I/O pins. There is space on the board for 8 current limiting resistors for LED drive.

## 2.2 3D Printed Parts

### 2.2.1 Racks

Each rack is a bbs rack2(10, 6, 4). The size is basically constrained by what my 3D printer can do. Each of these requires about 15 hours to print on my printer. Two of these can be bolted together side-by-side and fit in a 19 inch rack. This is the approximate size of the classic computer equipment. Multiple racks can be bolted together vertically as needed to provide panel space. Each rack has slots for two vertically oriented trays.

### 2.2.2 Processor Tray

The processor tray has mounting holes for the Raspberry Pi processor boad. It also has a 1/4 size perma-proto board from Adafruit (this may get changed to a half sized board) to provide space for miscellaneous wiring. Also on the tray is a LTC4311 I2C Extender/Active Terminator (p/n 4756 from Adafruit). This may not strictly be necessary, but since the I2C bus will be running off to

3

4 | CHAPTER 2. HARDWARE

several other boards, I thought that it might be a good idea. There is also a DB-9 connector that carries power and the I2C bus to the other trays.

### 2.2.3 Discrete I/O Tray

Each of these trays has one or two MCP23017 16 bit I/O expander chips with I2C interface. These trays would typically be mounted in the slot next to the panel. The tray has 4 DB-9 connections and can interface with up to 16 LEDs and 16 switches. One additional DB-9 connection is provided to connect the the power and I2C bus from the processor.

### 2.2.4 Address/Data Panels

The address/data panels provide 8 switches and LEDs numbered consecutively from right to left. The starting number is selectable in the model. Each panel has two cables (one for LEDs and one for switches) that attach to connectors on the discrete I/O boards. Enough of these need to be provided to account for all the address and data lines in the simulated processor. A system would typically have two or four of these panels for 16 or 32 bit systems. Note that there are many cases where the number of address lines does not match the number of data lines. In these cases panels would need to be provided for whichever number is greater.

### 2.2.5 Control Panel

At this point, without an actual CPU simulation, this is mostly a way to organize what needs to be in a relatively generic control panel. The following functions are needed:

- Read from a memory location.
- Write to a memory location.
- Stop/pause processor execution.
- Start processor execution at a specified address.
- Continue processor execution.
- Reset the processor.

The following switches are defined on the panel:

| • “Run”/“Pause” - The “Run” position allows program execution. The “Pause” position tem- porarily suspends execution. Moving the switch back to the “Run” position will continue

where the program left off.

| • “Start”/“Stop” - Moving the switch to the “Start” position loads a starting address to begin program execution. The “Stop” position halts a program and a new starting address will

need to be provided.

| • “Auto”/“Man” - The “Auto” position allows for remote control of the simulator via a web
interface. The “Man” position disables remote control.
| • “Addr”/“Data” - Selects display and entry of memory addresses or data.

2.2. 3D PRINTED PARTS | 5
- “Dep” deposits the switch value. If the “Addr”/“Data” switch is in the “Addr” position, a memory address is loaded. If the “Addr”/“Data” switch is in the “Data” position, the switch value is deposited in memory and the address incremented.
- “Exam” is used to examine memory at the current address. The address is incremented each time the switch is moved to the “Exam” position.
- Spare - an empty position reserved for future expansion.
- “Power”/“Off” - This will eventually be wired up to control power to the Raspberry Pi computer.

To Specify an Address

Note that if the word size is greater than 8 bits, some of the lower order address bits may be ignored.

- Toggle the desired address using the address/data switches.
- Move the “Addr”/“Data” switch to the “Addr” position.
- Move the “Dep” (deposit) switch to the “Dep” position.
- Once the LED for the “Dep” switch illuminates, move the switch to the unlabeled position.

To Read Memory

- Specify the starting address as described above.
- Move the “Addr”/“Data” switch to the “Data” position.
- Move the “Exam” switch to the “Exam” position.
- The contents of memory at the specified address will be displayed in the Address/Data LEDs.
- The “Addr”/“Data” switch can be used to toggle between display of the address and the data.
- Move the “Exam” switch to the unlabeled position. This increments the internal address pointer so that by toggling this switch a block of memory can be modified.

To Write Memory

- Specify the starting address as described above.
- Move the “Addr”/“Data” switch to the “Data” position.
- Toggle the desired data using the address/data switches.
- Move the “Dep” switch to the “Dep” position.
- The contents of memory at the specified address will be updated and displayed in the Address/Data LEDs.

6 | CHAPTER 2. HARDWARE
| • The “Addr”/“Data” switch can be used to toggle between display of the address and the
data.
| • Move the “Dep” switch to the unlabeled position. This increments the internal address pointer so that by toggling this switch a block of memory can be examined.

To Start Execution at a Specific Address

- Move the “Start”/“Stop” switch to the “Stop” position.
- Move the “Addr”/“Data” switch to the “Addr” position.
- Toggle the address using the address/data switches.
- Move the “Start”/“Stop” switch to the “Start” position.
| • If the “Run”/“Pause” switch is in the “Pause” position, move it to the “Run” position.

### 2.2.6 Mode Panel

This is a display only panel to show the processor and memory access modes. It has seven labeled positions in two groups separated by a spare. The first group is the processor mode. This indicates which of four possible modes (User, Supervisor, Executive, or Kernel) the processor is in. The second group indicates the type of memory access. There are three possibilities: Instruction (read-only), Data (read/write), and Interrupt (read-only).

## 2.3 Assembly

# Chapter 3

# Software

## 3.1 Overview

## 3.2 Simulation

## 3.3 Web Server

7

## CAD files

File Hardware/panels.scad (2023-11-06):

//
//  These are a collection of panels for the Raspberry Pi mainframe simulator.  The panels
//  include switches and LEDs and a couple of LCD displays.  Select which panels you
//  want, then you can render them for printing.  My printer is not big enough to print
//  them all in one batch.
//
use <../../Things/bbs_connectors.scad>
use <../../Things/bbs_leds.scad>
use <../../Things/bbs_panel.scad>
use <../../Things/bbs_switches.scad>

width = 220;
//title_font = "Blackmoor LET";
title_font = "Liberation Sans::style=Bold";
//number_font = "Blackmoor LET";
number_font = "Liberation Sans::style=Bold";
//
//  Module for LED PCB for fit checking.  Since this is, at the current time, specific to this
//  project, the models are included here, rather than in the bbs_boards file in the Things
//  repository.
//
module board_led_standoffs(height, radius, facets)
{
  union()
  {
    translate([5.5, 14.25, -0.1]) cylinder($fn=facets, h=height, r=radius);
    translate([145.5, 14.25, -0.1]) cylinder($fn=facets, h=height, r=radius);
  }
}

module board_led()
{
  difference()
  {
    union()
    {
      color("red") cube([152, 19.25, 1.4]);
      for(x = [0:7])
      {
        translate([5.5 + x*20, 5.5 , 1.4]) rotate([0, 0, -90]) bbs_led_C5SMF("green");
      }
      translate([80.575, 13.35, 0]) rotate([180, 0, 180]) bbs_2x5_rt();
    }
    board_led_standoffs(4, 1.25, 12);
  }
}
//
//  Module for supporting the LED PCB
//
module board_support(height)
{
  translate([0, 0, -height]) cube([5, 152, height]);
  translate([0, 0, -(height + 2)]) cube([3, 152, 2]);
  translate([0, 0, -(height + 3)]) cube([4, 152, 1]);
}
//
//  This panel has mounting for 8 switches and LEDs.  Numbers are embossed between the
//  switch and LEDs.  The number values increase from right to left starting with the
//  passed "start" value.
//
module new_panel_switch(start, board)
{
  spacing = 20;
  led_height = 5;
  led_x = 40;
  union()
  {
    if (board)
    {
      translate([led_x - 7, 185.5, -(led_height + 1.75)]) rotate([0, 0, -90]) board_led();
    }
    difference()
    {
      union()
      {
        bbs_panel(10, 4);
        translate([led_x - 7, 185.5, -led_height]) rotate([0, 0, -90]) board_led_standoffs(led_height + 1, 2.5, 12);
        translate([led_x - 10, 33.5, 0]) board_support(led_height);
      }
      union()
      {
        for(a = [1:8])
        {
          y = width/2 - (4.5-a)*spacing;
          translate([15, y, -0.1]) bbs_spdt_switch_cutout(2.2);
          translate([40, y, -0.1]) bbs_led_oval(2.2);
          translate([28, y, 1.5]) linear_extrude(height = 0.6) rotate([0, 0, -90])
              text(str(a + start - 1), halign="center", valign="center", size=6,
                font=number_font);
        }
        translate([5, width/2-1, 1.5]) cube([25, 2, 1]);
        translate([50, width/2-1, 1.5]) cube([25, 2, 1]);
        translate([60, 200, 1.5]) linear_extrude(height = 0.6) rotate([0, 0, -90])
              text("Addr/Data", halign="left", valign="center", size=7,
                font=title_font);
        translate([led_x - 7, 185.5, -(led_height + 0.1)]) rotate([0, 0, -90]) board_led_standoffs(led_height + 6, 1.25, 12);
      }
    }
  }
}

module panel_switch(start)
{
  spacing = (width-30)/8;
  union()
  {
    difference()
    {
      bbs_panel(10, 4);
      union()
      {
        for(a = [1:8])
        {
          y = width/2 - (4.5-a)*spacing;
          translate([15, y, -0.1]) bbs_spdt_switch_cutout(2.2);
          if(a < 8)
          {
            translate([43, y + spacing/2 - 2.5, -0.1]) cube([2, 5, 2.2]);
            translate([35, y + spacing/2 - 2.5, -0.1]) cube([2, 5, 2.2]);
          }
          translate([40, y, -0.1]) bbs_led_oval(2.2);
          translate([28, y, 1.5]) linear_extrude(height = 0.6) rotate([0, 0, -90])
              text(str(a + start - 1), halign="center", valign="center", size=6,
                font=number_font);
        }
        translate([5, width/2-1, 1.5]) cube([25, 2, 1]);
        translate([50, width/2-1, 1.5]) cube([25, 2, 1]);
        translate([60, 200, 1.5]) linear_extrude(height = 0.6) rotate([0, 0, -90])
              text("Addr/Data", halign="left", valign="center", size=7,
                font=title_font);
      }
    }
  }
}//
//  This panel just has the specified text on a 1 frame high panel.  It is used as a
//  nameplate.
//
module panel_nameplate(name)
{
  difference()
  {
    bbs_panel(10, 1);
    translate([10, 200, 1.5]) linear_extrude(height = 0.6) rotate([0, 0, -90])
              text(name, halign="left", valign="center", size=7,
                font=title_font);

  }
}
//
//  This panel has various switches and LEDs for controls and status
//

module panel_control()
{
  spacing = (width-30)/8;
  led_x = 55;
  switch_x = 25;
  on_labels  = ["Run", "Start", "Auto", "Addr", "Dep", "Exam", "Rdy", "Power"];
  off_labels = ["Pause", "Stop", "Man", "Data", "", "", "", "Off"];
  union()
  {
    difference()
    {
      bbs_panel(10, 4);
      union()
      {
        for(a = [1:8])
        {
          y = width/2 - (4.5-a)*spacing;
          //
          //  No switch for Rdy LED.
          //
          if(a != 2)
          {
            translate([switch_x, y, -0.1]) bbs_spdt_switch_cutout(2.2);
          }
          if(a < 8)
          {
            translate([led_x + 3, y + spacing/2 - 2.5, -0.1]) cube([2, 5, 2.2]);
            translate([led_x - 4, y + spacing/2 - 2.5, -0.1]) cube([2, 5, 2.2]);
          }
          translate([led_x, y, -0.1]) bbs_led_oval(2.2);
          translate([switch_x + 11, y, 1.5]) linear_extrude(height = 0.6) rotate([0, 0, -90])
              text(on_labels[8 - a], halign="center", valign="baseline", size=6,
                font=number_font);
          translate([switch_x - 15, y, 1.5]) linear_extrude(height = 0.6) rotate([0, 0, -90])
              text(off_labels[8 - a], halign="center", valign="baseline", size=6,
                font=number_font);
        }
        translate([70, 200, 1.5]) linear_extrude(height = 0.6) rotate([0, 0, -90])
              text("Control", halign="left", valign="center", size=7,
                font=title_font);
      }
    }
  }
}
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

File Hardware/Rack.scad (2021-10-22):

use <../../Things/bbs_rack.scad>

screw_rad = 4.5/2;
hole_rad = 5.0;
//
//  Note that this flange is not symmetrical.  You can't just print two of them, one of them
//  will need to be a reflection.  Otherwise the holes won't line up properly.
//
module flange(frames, off)
{
  difference()
  {
    union()
    {
      cube([frames*20, 37.3, 2]);
      cube([frames*20, 2, 20]);
    }
    union()
    {
      for(a = [10:20:(frames*20)])
      {
        translate([a, -1, 10]) rotate([-90, 0, 0]) cylinder(r=screw_rad, h=6, $fn=12);
      }
      for(a = [off:25.2:(frames*20)])
      {
        translate([a, 37.2-12, -1]) cylinder(r=hole_rad, h=6);
      }
    }
  }
}

//rotate([0, 0, 90]) bbs_rack2(10, 6, 4);
//flange(10, 10);
scale([1, -1, 1]) flange(10, 10);

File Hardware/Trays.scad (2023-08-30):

//
//  Tray for holding the Arduino Due and some extra boards.
//
use <../../Things/bbs_tray.scad>
use <../../Things/bbs_breadboard.scad>
use <../../Things/bbs_arduino.scad>
use <../../Things/bbs_constants.scad>
use <../../Things/bbs_connectors.scad>
use <../../Things/bbs_boards.scad>
use <../../Things/bbs_RaspberryPi.scad>

module motherboard_tray()
{
  difference()
  {
    union()
    {
      bbs_tray(10, 5, false);
    }
    union()
    {
      translate([85, 25, -1]) rotate([0, 0, 90]) bbs_d_cutout(1, 5);
      translate([63, 25, -1]) rotate([0, 0, 90]) bbs_d_cutout(1, 5);
      translate([41, 25, -1]) rotate([0, 0, 90]) bbs_d_cutout(1, 5);
      translate([10, 50, -1]) minkowski()
      {
        cube([100, 150, 10]);
        cylinder(r=1, h=10);
      }
    }
  }
}

rpi_x = 60;
rpi_y = 30;
q_proto_x = 70;
q_proto_y = 120;
module rpi_tray()
{
  screw_size = 3*screw_6_size()/4;
  screw_hole = screw_6_size()/2;
  difference()
  {
    union()
    {
      bbs_tray(10, 3, false);
      translate([rpi_x, rpi_y, 3]) rotate([0, 0, 90]) rPi3_standoffs(5, screw_size, 12);
      translate([q_proto_x, q_proto_y, 3]) rotate([0, 0, 90]) bbs_quarter_permaprotoboard_standoffs(5, screw_size, 12);
      translate([73, 8, 0]) cube([5, 35, 20]);
    }
    union()
    {
      translate([rpi_x, rpi_y, -2]) rotate([0, 0, 90]) rPi3_standoffs(5 + 6, screw_hole, 12);
      translate([q_proto_x, q_proto_y, -2]) rotate([0, 0, 90]) bbs_quarter_permaprotoboard_standoffs(5 + 6, screw_hole, 12);
      translate([80, 25, 12]) rotate([0, -90, 0]) rotate([0, 0, 90]) bbs_d_cutout(1, 10);
      translate([10, 10, -1]) minkowski()
      {
        cube([60, 35, 10]);
        cylinder(r=1, h=10);
      }
      translate([10, 60, -1]) minkowski()
      {
        cube([60, 45, 10]);
        cylinder(r=1, h=10);
      }
      translate([10, 130, -1]) minkowski()
      {
        cube([60, 20, 10]);
        cylinder(r=1, h=10);
      }
      translate([10, 170, -1]) minkowski()
      {
        cube([60, 25, 10]);
        cylinder(r=1, h=10);
      }
    }
  }
}

breakout_x = 75;
breakout_y = 120;
module rpi_tray_new()
{
  screw_size = 3*screw_6_size()/4;
  screw_hole = screw_6_size()/2;
  difference()
  {
    union()
    {
      bbs_tray(10, 3, false);
      translate([rpi_x, rpi_y, 3]) rotate([0, 0, 90]) rPi3_standoffs(5, screw_size, 12);
      translate([breakout_x, breakout_y, 3]) rotate([0, 0, 90]) bbs_Ribbon10_standoffs(5, screw_size, 12);
    }
    union()
    {
      translate([rpi_x, rpi_y, -2]) rotate([0, 0, 90]) rPi3_standoffs(5 + 6, screw_hole, 12);
      translate([breakout_x, breakout_y, -2]) rotate([0, 0, 90]) bbs_Ribbon10_standoffs(5 + 6, screw_hole, 12);
      translate([10, 10, -1]) minkowski()
      {
        cube([60, 35, 10]);
        cylinder(r=1, h=10);
      }
      translate([10, 60, -1]) minkowski()
      {
        cube([60, 45, 10]);
        cylinder(r=1, h=10);
      }
      translate([10, 120, -1]) minkowski()
      {
        cube([50, 70, 10]);
        cylinder(r=1, h=10);
      }
    }
  }
}

half_proto_x = 55;
half_proto_y = 10;
module panel_tray()
{
  screw_size = 3*screw_6_size()/4;
  screw_hole = screw_6_size()/2;
  difference()
  {
    union()
    {
      bbs_tray(10, 3, false);
      translate([half_proto_x, half_proto_y, 3]) rotate([0, 0, 90])
        bbs_half_permaprotoboard_standoffs(3, screw_size, 12);
      translate([half_proto_x, half_proto_y+90, 3]) rotate([0, 0, 90])
        bbs_half_permaprotoboard_standoffs(3, screw_size, 12);
      translate([73, 8, 0]) cube([5, 35, 20]);
    }
    union()
    {
      translate([half_proto_x, half_proto_y, -2]) rotate([0, 0, 90]) bbs_half_permaprotoboard_standoffs(5 + 6, screw_hole, 12);
      translate([half_proto_x, half_proto_y+90, -2]) rotate([0, 0, 90]) bbs_half_permaprotoboard_standoffs(5 + 6, screw_hole, 12);
      translate([80, 25, 12]) rotate([0, -90, 0]) rotate([0, 0, 90]) bbs_d_cutout(1, 10);
      translate([70, 60, -1]) rotate([0, 0, 90]) bbs_d_cutout(1, 5);
      translate([70, 95, -1]) rotate([0, 0, 90]) bbs_d_cutout(1, 5);
      translate([70, 130, -1]) rotate([0, 0, -90]) bbs_d_cutout(1, 5);
      translate([70, 165, -1]) rotate([0, 0, -90]) bbs_d_cutout(1, 5);
      translate([35, 9, -1]) minkowski()
      {
        cube([25, 191, 10]);
        cylinder(r=1, h=10);
      }
      translate([0, 9, -1]) minkowski()
      {
        cube([20, 191, 10]);
        cylinder(r=1, h=10);
      }
    }
  }
}

module IO_tray()
{
  screw_size = 3*screw_6_size()/4;
  screw_hole = screw_6_size()/2;
  board_x = 77;
  board_y = 90;
  difference()
  {
    union()
    {
      bbs_tray(10, 3, false);
      translate([board_x, board_y, 0.1]) rotate([0, 0, 90]) bbs_GPIO_standoffs(7, screw_size, 10);
    }
    union()
    {
      translate([board_x, board_y, 0]) rotate([0, 0, 90]) bbs_GPIO_standoffs(10, screw_hole, 10);
      translate([0, 9, -1]) minkowski()
      {
        cube([25, 191, 10]);
        cylinder(r=1, h=10);
      }
      translate([42, 9, -1]) minkowski()
      {
        cube([26, 191, 10]);
        cylinder(r=1, h=10);
      }
    }
  }
}

//rotate([0, 0, 90])
union()
{
//  rpi_tray_new();
//  color("red") translate([rpi_x, rpi_y, 10]) rotate([0, 0, 90]) bbs_rPi3();
//  color("red") translate([breakout_x, breakout_y, 10]) rotate([0, 0, 90]) bbs_Ribbon10();
  IO_tray();
//  translate([77, 90, 10]) rotate([0, 0, 90]) bbs_GPIO();
//  color("white") translate([half_proto_x, half_proto_y, 5]) rotate([0, 0, 90]) bbs_half_permaprotoboard();
//  color("white") translate([half_proto_x, half_proto_y+90, 5]) rotate([0, 0, 90]) bbs_half_permaprotoboard();
}

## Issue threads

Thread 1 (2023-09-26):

Correct Spelling

BrentSeidel, 2023-09-26:
Correct spelling of "engergize" on power panel.

BrentSeidel, 2023-11-06:
Spelling corrected.

Closed 2023-11-06.

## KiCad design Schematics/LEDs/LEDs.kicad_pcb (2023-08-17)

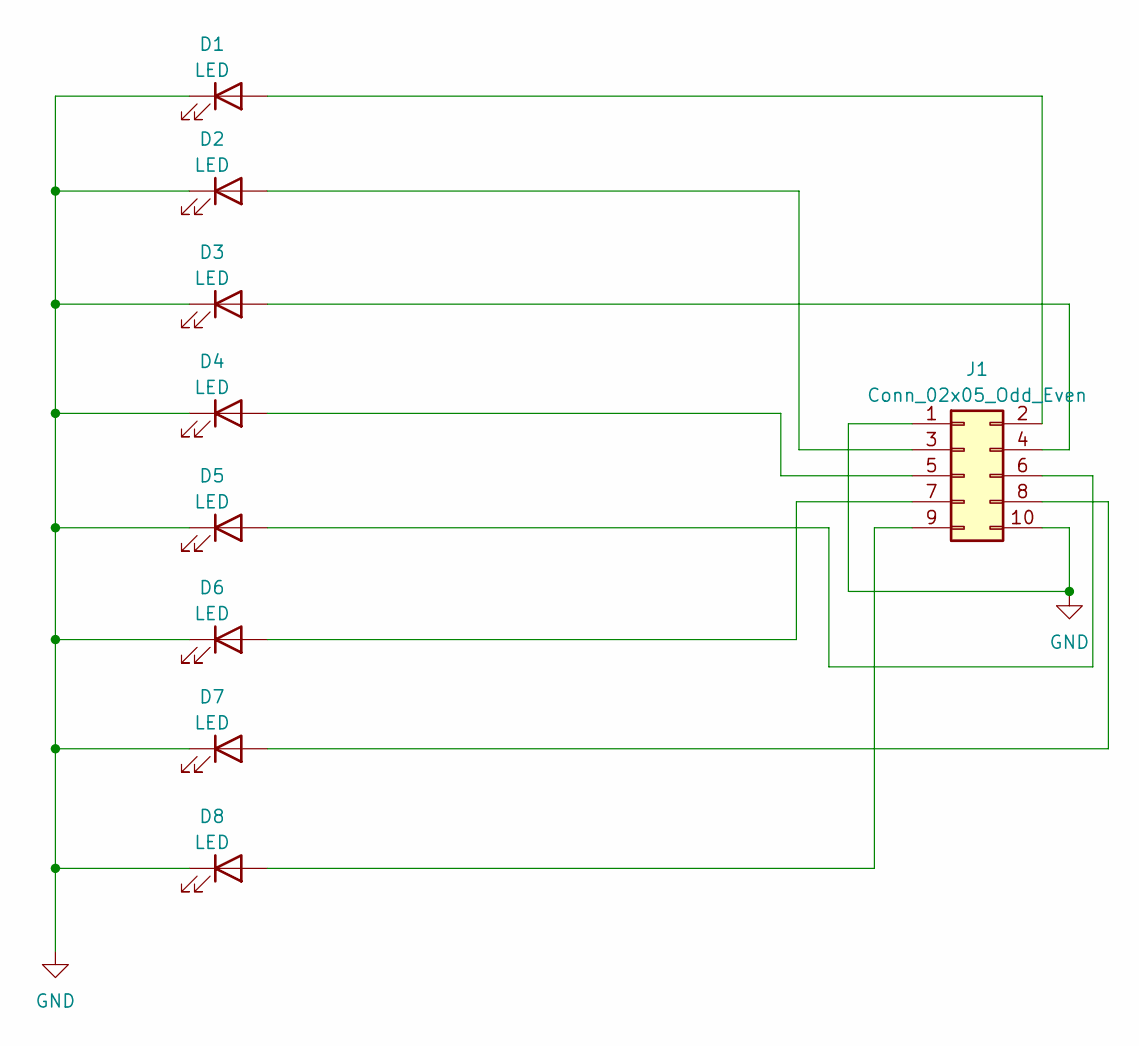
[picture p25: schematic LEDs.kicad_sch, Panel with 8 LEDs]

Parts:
D1, D2, D3, D4, D5, D6, D7, D8: LED; LED_D5.0mm_Clear
J1: Conn_02x05_Odd_Even; PinHeader_2x05_P2.54mm_Horizontal

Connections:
GND: D1.1 (K), D2.1 (K), D3.1 (K), D4.1 (K), D5.1 (K), D6.1 (K), D7.1 (K), D8.1 (K), J1.1, J1.10
unnamed: D1.2 (A), J1.2
unnamed: D2.2 (A), J1.3
unnamed: D3.2 (A), J1.4
unnamed: D4.2 (A), J1.5
unnamed: D5.2 (A), J1.6
unnamed: D6.2 (A), J1.7
unnamed: D7.2 (A), J1.8
unnamed: D8.2 (A), J1.9

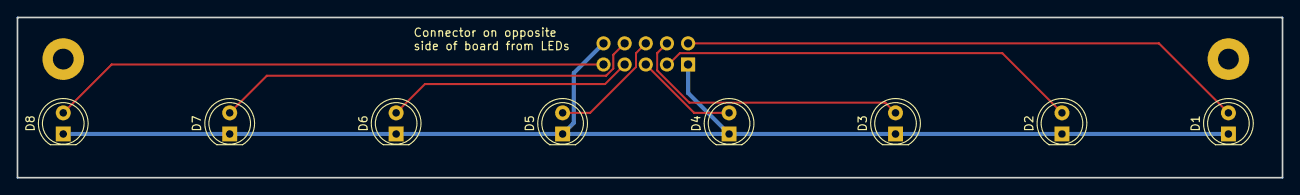
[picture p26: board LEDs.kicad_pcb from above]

Board: 2 copper layers, 152.0 x 19.2 mm, 11 parts (1 on the bottom side), 9 nets.

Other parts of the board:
REF1, REF2: MountingHole_2.5mm_Pad

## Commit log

2021-09-12 First commit with OpenSCAD files for 3D printed objects.
    [Rack.scad, Trays.scad, combined.scad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]
2021-09-14 Use enumeration with representation clauses for MCP23017 devices so that the addresses are encapsulated.
    Update project file to reference Ada-Web-Server.
2021-09-14 Typo correction - change i2c.SWITCH_MSW to i2c.SWITCH_LSW.
2021-09-15 Add web server - it doesn't do much yet. Change patterns to a task.
    [config.txt]
2021-09-15 Further web server development - add a page to show hardware configuration.
    [config.txt]
2021-09-17 Start working on documentation and add documentation to web pages.
    [config.txt, panels.scad]
2021-09-21 Restructure code a bit and start adding AJAX for interfacing to the simulator via a web page.
    [config.txt, panels.scad]
2021-09-21 Updates to start to allow remote control of simulator.
    [config.txt]
2021-09-22 Some doc and hardware updates. Work on interface between i2c and simulator.
    [panels.scad]
2021-09-22 Work on simulator interface some more.
    [Trays.scad]
2021-09-23 Add display of panel register values.
    [config.txt]
2021-09-23 Documentation updates and a minor update to control panel labels.
    [panels.scad]
2021-09-28 Documentation updates and add some assembly pictures.
2021-09-29 Documentation updates with figures to add instructions for wiring LEDs on panels.
2021-10-05 Documentation updates. Add a power panel. S/W updates to start working witn control and mode panels.
    [panels.scad]
2021-10-06 Documentation updates and add a couple of assembly images.
2021-10-08 Documentation updates - add more assembly instructions and photos.
2021-10-08 Update hardware configuration code to support mode/control LEDs.
2021-10-08 Extend test patterns to include mode/control LEDs.
2021-10-10 Update software to be able to test control switches.
2021-10-11 Initial code to let the auto/man switch enable/disable remote control.
2021-10-12 Update documentation to show switch wiring.
    Increase size of rack flanges and work on incorporating control switch
    functions into software.
    Process pictures to reduce their size and the size of the documents.
    Squashed some commits to avoid sending too large files to GitHub.
    [Rack.scad]
2021-10-12 Move exception handler to top level to turn out the lights when exiting. Some changes to switch change logic to clear changes at the end of the loop.
2021-10-13 More work on control switch logic and reduction of redundant I2C messages.
2021-10-13 Allow web server to request simulator exit
    [config.txt]
2021-10-15 Documentation updates and some minor internal changes to simulator. Adjust the spacing of mounting holes for rack adapters.
    [Rack.scad]
2021-10-20 Add program to test lights and switches
2021-10-22 Documentation updates.
    [Rack.scad]
2022-01-11 Make switch register values read-only outside of sim package.
2022-01-12 Fix bug related to detecting switch changes.
2022-01-18 Change way that Address/Data switch is handled. Start preparing simulator for breakout into a separate repository.
2022-01-18 Move simulators into BBS package hierarchy. Add web page to show simulator information and register values.
    [config.txt]
2022-01-21 Moved simulator files into Sim-CPU repository and made updates to point to that project. Also fixed a couple typos in comments in i2c.ads
2023-05-28 Start working on schematics and board layout for I/O board. If nothing else, the schematics will provide some documentation about how things should be wired up. Note that this may not be consistent w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
    [IOBoard.kicad_pcb, IOBoard.kicad_sch]
2023-06-13 Update schematic and PCB to use resistor symbols instead of jumpers.
    [IOBoard.kicad_pcb, IOBoard.kicad_sch]
2023-06-19 Update PCB to use SMD resistors and rectangular connectors. This lets the PCB shrink some more and it may be easier to crimp rectangular connectors onto ribbon cable than to solder a bunch of D-9 con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
    [IOBoard.kicad_pcb, IOBoard.kicad_sch]
2023-07-09 Update schematic to add resisters on inputs as well. Submitted PCB for production. Once PCBs are received, assembled, tested, and working, I'll update documentation.
    [IOBoard.kicad_pcb, IOBoard.kicad_sch]
2023-07-24 Fix schematic error and re-layout board. Start a tray to hold board.
    [IOBoard.kicad_pcb, IOBoard.kicad_sch, Trays.scad]
2023-07-26 More updates to I/O board PCB layout.
    [IOBoard.kicad_pcb]
2023-07-28 Updates to PCB layout to add silkscreen blocks for notes.
    [IOBoard.kicad_pcb]
2023-08-09 Updates to panels. Delete unused stuff and modify labels.
    [combined.scad, panels.scad]
2023-08-11 Remove I/O Board design now that it has been moved to the Circuits repository.
    [IOBoard.kicad_pcb, IOBoard.kicad_sch]
2023-08-14 Update README.md
    Correct typo in link to Circuits repository.
2023-08-15 Work on CPU tray to incorporate the breakout board from the circuits repository. Work on I/O tray to use the new GPIO board from the circuits repository.
    [Trays.scad]
2023-08-15 Use Ribbon-10 breakout board model instead of local breakout model.
    [Trays.scad]
2023-08-17 Add PCB for LEDs and update panels to use the PCB.
    [LEDs.kicad_pcb, LEDs.kicad_sch, panels.scad]
2023-08-18 Update the README to give current status.
2023-08-30 Adjust the IO tray so that the IO board lines up with the connector from the processor board. This makes the ribbon cable easier to run.
    [Trays.scad]
2023-09-01 Start working on assmebly instructions for new hardware with custom PCBs.
2023-09-01 Update panels for LED PCBs.
    [panels.scad]
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2023-09-04 Updates to documentation to include assembly of panels.
2023-09-19 Update to README about power supply and consumption/
2023-11-06 Correct spelling of "engergisze" on power panel, per Issue #1.
    [panels.scad]
2023-11-06 Update README.md
    Delete extra backslash from LED PCB heading.
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2024-03-20 Call initialization for 68000 CPU. Add sample OS and Task files for 68000 CPU. Move project to use alire.
2024-05-07 Add missing attach of clock to 68000 init. Add mux device to 68000 init.
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
